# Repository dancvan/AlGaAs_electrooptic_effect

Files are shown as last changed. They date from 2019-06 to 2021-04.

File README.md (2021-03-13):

#AlGaAs_electro-optic_effect
This repository is intended to hold all related notes/work related to the measurement of the electro-optic effects (both the pockels and the piezoelectric effects) at the SU gravitational wave physics lab

Navigating this repository:

3D_prints:
- Contains all 3D printed designs used for this experiment (file formats: .stl, .shapr)

code:
- notebooks -> a high number of jupyter notebooks primarily used for quick computations and plotting. For instance, one notebook in lab_tools called beam_scans provides an easy routine to do a least squares fit from an .xlsx file.  
- fea_electrodes -> directory contains all files related to the simulation of the electrode system to produce a reasonable electric field estimate within the AlGaAs coating (both disk and split electrode systems)
- py_packages -> contains consistently used computations and operations (for instance, importing a model dataset from ltspice or the calibration of the meaasured error signal voltage spectra within the PDH loop to a displacement spectra
- finesse -> currently not utilized very much but might possibly be updated with tabletop simulations

documents:
- contains various books, datasheets, internal notes, and related publications that I found relevant to the project

measurements:
- all measured data. Categorized by measurement type and is stored within a directory that labels the date of the measurement taken.

results:
- contains a lot of .hdf5 files that can be traced back reading through the code/py_packages/pockels_cal.py calibration package. It also contains figures depicting experimental concept sketches and .stl files as well as group meeting updates that organize the results into something a little more comprehensive.

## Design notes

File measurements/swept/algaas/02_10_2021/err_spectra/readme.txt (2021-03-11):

This set of measurements starts from 2.6 kHz and goes up to 21 kHz. Peaks are driven at approximately 800 Hz intervals from 3kHz to 20.6kHz.

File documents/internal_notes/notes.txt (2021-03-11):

Stefan suggested looking at whether the frequency noise of the mephisto to see if it would be a limiting factor of our measurment
* When looking into frequency noise, you may ask how that would couple into our phase measurement?
* A key is to see how the circulating power differs when adjusting the frequency or the effective optical length of the cavity (see notes for calculating the circulating power and verifying that a change in frequency is equivalent to changing the effective optical length of the cavity)
* Once it was established that a change in frequency was equivalent to a change of effective optical length of the cavity, in terms of circulating power, we can calculate if the optical length change that we wish to measure relative to the total length of the cavity is larger than the change in frequency relative to the frequency of the laser. 
* Marty estimates that the change in optical length is 4.5e-10 m/V so I'll assume that for a half a meter cavity that the effect will be 9e-10 
* I estimate based on the specs sheet that a 1MHz change to a 281e12 Hz laser is around 3.54e-9
    - INCORRECT
    - This initial estimate is based on the slew rate of the laser
* The frequency noise of the laser is characterized in the mephisto spec sheets as a spectrum from 1Hz to 10 kHz 
    - How to translate this Hz/\sqrt(Hz) figure into phase noise?
    - Let's disentangle the figure....
    - The PSD for frequency noise essentially states how large the frequency wiggles at a particular frequency (feels kinda meta), but then again, what does this tell us about our phase noise?
    - We know that we can characterize length noise by taking the ratio of the change in length over the length, and equivalently we can do the same for frequency (take the change in frequency over the frequency to get frequency noise). But this doesn't seem explicit from the spectrum. the frequency noise is weighted by the amount of power it has in the spectrum... how to express that?
    - Let's start with the largest value in the freqeuncy amplitude noise spectrum, say 10^4 Hz/sqrt(Hz), let's translate this into phase noise:
        ~ the amplitude around 1Hz is 10^4 which means that there should be 10,000 Hz deviation around 1Hz?
        ~ This is definitely the case. Let's take the largest frequency variation and work with that in termso our our above expression: 
        ~ (10,000)/()

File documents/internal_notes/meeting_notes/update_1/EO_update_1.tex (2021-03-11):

%%%%%%%%%%%%%%%%%%%%%%%%%%%%%%%%%%%%%%%%%
% Beamer Presentation
% LaTeX Template
% Version 1.0 (10/11/12)
%
% This template has been downloaded from:
% http://www.LaTeXTemplates.com
%
% License:
% CC BY-NC-SA 3.0 (http://creativecommons.org/licenses/by-nc-sa/3.0/)
%
%%%%%%%%%%%%%%%%%%%%%%%%%%%%%%%%%%%%%%%%%

%----------------------------------------------------------------------------------------
%	PACKAGES AND THEMES
%----------------------------------------------------------------------------------------

\documentclass{beamer}

\mode<presentation> {

% The Beamer class comes with a number of default slide themes
% which change the colors and layouts of slides. Below this is a list
% of all the themes, uncomment each in turn to see what they look like.

%\usetheme{default}
%\usetheme{AnnArbor}
%\usetheme{Antibes}
%\usetheme{Bergen}
%\usetheme{Berkeley}
%\usetheme{Berlin}
%\usetheme{Boadilla}
%\usetheme{CambridgeUS}
%\usetheme{Copenhagen}
%\usetheme{Darmstadt}
%\usetheme{Dresden}
%\usetheme{Frankfurt}
%\usetheme{Goettingen}
%\usetheme{Hannover}
%\usetheme{Ilmenau}
%\usetheme{JuanLesPins}
%\usetheme{Luebeck}
\usetheme{Madrid}
%\usetheme{Malmoe}
%\usetheme{Marburg}
%\usetheme{Montpellier}
%\usetheme{PaloAlto}
%\usetheme{Pittsburgh}
%\usetheme{Rochester}
%\usetheme{Singapore}
%\usetheme{Szeged}
%\usetheme{Warsaw}

% As well as themes, the Beamer class has a number of color themes
% for any slide theme. Uncomment each of these in turn to see how it
% changes the colors of your current slide theme.

%\usecolortheme{albatross}
%\usecolortheme{beaver}
%\usecolortheme{beetle}
%\usecolortheme{crane}
%\usecolortheme{dolphin}
%\usecolortheme{dove}
%\usecolortheme{fly}
%\usecolortheme{lily}
%\usecolortheme{orchid}
%\usecolortheme{rose}
%\usecolortheme{seagull}
%\usecolortheme{seahorse}
%\usecolortheme{whale}
%\usecolortheme{wolverine}

%\setbeamertemplate{footline} % To remove the footer line in all slides uncomment this line
\setbeamertemplate{footline}[page number] % To replace the footer line in all slides with a simple slide count uncomment this line

\setbeamertemplate{navigation symbols}{} % To remove the navigation symbols from the bottom of all slides uncomment this line
}

\usepackage{graphicx} % Allows including images
\usepackage{booktabs} % Allows the use of \toprule, \midrule and \bottomrule in tables
%\usepackage {tikz}
\usepackage{tkz-graph}
\usepackage{hyperref}
\usepackage{ulem}
\hypersetup{
    colorlinks=true,
    linkcolor=blue,
    filecolor=magenta,
    urlcolor=cyan,
}
\GraphInit[vstyle = Shade]
\tikzset{
  LabelStyle/.style = { rectangle, rounded corners, draw,
                        minimum width = 2em, fill = yellow!50,
                        text = red, font = \bfseries },
  VertexStyle/.append style = { inner sep=5pt,
                                font = \normalsize\bfseries},
  EdgeStyle/.append style = {->, bend left} }
\usetikzlibrary {positioning}

%\usepackage {xcolor}
\definecolor {processblue}{cmyk}{0.96,0,0,0}
%----------------------------------------------------------------------------------------
%	TITLE PAGE
%----------------------------------------------------------------------------------------

\title[Short title]{Piezoelectric effect measurement update (Noise and initial design considerations)} % The short title appears at the bottom of every slide, the full title is only on the title page

\author{Ari Pedersen, Danny Vander-Hyde} % Your name
\institute[Syracuse University] % Your institution as it will appear on the bottom of every slide, may be shorthand to save space
{
Syracuse University\\ % Your institution for the title page
\medskip
}
\date{June 21, 2019} % Date, can be changed to a custom date

\begin{document}

\begin{frame}
\titlepage % Print the title page as the first slide
\end{frame}

\begin{frame}
\frametitle{Overview} % Table of contents slide, comment this block out to remove it
\tableofcontents % Throughout your presentation, if you choose to use \section{} and \subsection{} commands, these will automatically be printed on this slide as an overview of your presentation
\end{frame}

%----------------------------------------------------------------------------------------
%	PRESENTATION SLIDES
%----------------------------------------------------------------------------------------

%------------------------------------------------
\section{How big is the Piezoelectric effect?}
\begin{frame}{Some preliminary figures}
\begin{itemize}
  \item According to Marty Fejer $\frac{\partial \phi}{\partial \mathrm{E}} \approx 4.5*10^{-10} \frac{\mathrm{m}}{\mathrm{V}}$
  \item Conservatively we can attempt to create a setup that would generate Electric fields on the order of 10 V / 2.5 cm = \sout{400} \textcolor{red}{40} V/m \textcolor{red}{(Apparently I can't math)}
  \item Could also up the voltage and decrease the distance to get a larger effect
  \item This would lead to an effect of $1.8*10^{-8} \; [\mathrm{rad}]$ or $3.05*10^{-14} [\mathrm{m}]$
  \item This is for a single layer so we could multiply by the number of AlGaAs layers? (Maybe increases the effect by an order of magnitude?)
\end{itemize}
\end{frame}

\section{Competing with laser frequency noise}
\begin{frame}{Light source: Mephisto 2000 NE}
 \begin{figure}[H]
  \centering
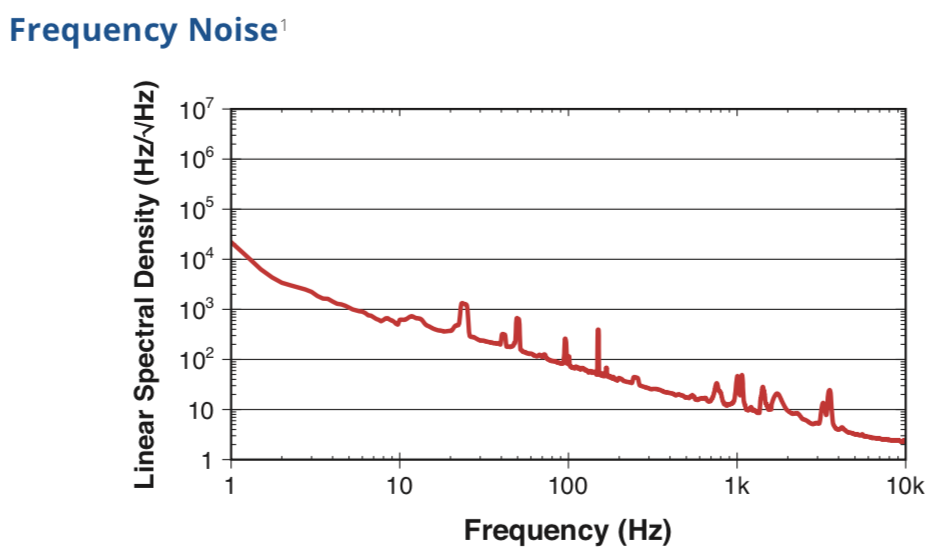
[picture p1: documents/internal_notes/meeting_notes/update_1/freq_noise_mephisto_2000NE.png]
  
 \end{figure}
\end{frame}

\begin{frame}{Frequency noise to phase noise}
\begin{itemize}
  \item Assuming that the largest laser frequency fluctuations ($\Delta f_\mathrm{laser}$) 11,500 Hz away from the carrier frequency. Can calculate this as phase noise $\big(\frac{\Delta f_{\mathrm{laser}}}{f_{\mathrm{laser}}}\big)$ on the order of $4.08*10^{-11}\; [\mathrm{rad}]$
  \item If we are to use a simple Fabry-Perot cavity to measure this effect, we would need:
$$\frac{\Delta f_{\mathrm{laser}}}{f_{\mathrm{laser}}}< \frac{\Delta L_{\mathrm{cav}}}{L_{\mathrm{cav}}}$$
Where I am considering $\Delta L_{\mathrm{cav}}$ to be the induced length change due to the piezoelectric effect.
  \item Assuming we have a 10 cm length cavity we can estimate $\frac{3.05*10^{-14}}{.01} = 3.05*10^{-12}\; [\mathrm{rad}]$ which lies an order of magnitude below the effect we wish to measure. :(
  \item Can modulate the electric field at some higher frequency where the frequency noise is less of an issue (how fast can we modulate the field and still notice the effect? $\rightarrow$ Impulse / Step response analysis)
\end{itemize}
\end{frame}

\begin{frame}{Frequency noise to phase noise \textcolor{red}{Stefan notes}}
\begin{itemize}
  \item Stefan mentioned that up to 10kHz you can assume that Piezo-electric response of the coating is flat up to 10kHz
  \item If we are to use a simple Fabry-Perot cavity to measure this effect, we would need:
$$\frac{\Delta f_{\mathrm{laser}}}{f_{\mathrm{laser}}}< \frac{\Delta L_{\mathrm{cav}}}{L_{\mathrm{cav}}}$$
Where I am considering $\Delta L_{\mathrm{cav}}$ to be the induced length change due to the piezoelectric effect.
  \item Assuming we have a 10 cm length cavity we can estimate $\frac{3.05*10^{-14}}{.01} = 3.05*10^{-12}\; [\mathrm{rad}]$ which lies an order of magnitude below the effect we wish to measure. :(
  \item Can modulate the electric field at some higher frequency where the frequency noise is less of an issue (how fast can we modulate the field and still notice the effect? $\rightarrow$ Impulse / Step response analysis)
\end{itemize}

\end{frame}

\begin{frame}{PDH locking}

\begin{itemize}
  \item First attempt to suppress laser frequency noise while keeping simple cavity design in mind.
  \item Black states (\href{https://youtu.be/tX884B8GrEE}{ref}) that a closed loop PDH system can suppress frequency noise ($n$) below the reference cavity pole frequency by a factor of $$\frac{1}{1 + H(s)*D(s)*K(s)}$$
Where H(s) [Hz/V] is the laser transfer function, D(s) [V/Hz] is the PDH transfer function, and K(s) is the servo gain.
  \item Don’t have exact values to propose but this could be a place to start.
  \item Propose we use the LIGO PMC we have on the AMM table as refrence cavity. (Might want to double check how destructive this could be to phase camera peeps)
  \item If this does not provide enough suppression, we might have to move on to an interferometer design.

\end{itemize}
\end{frame}

\section{Electrode / Sample mount}
\begin{frame}{Electrode design}
\begin{itemize}
  \item Am thinking of machining a thin square aluminum plate significantly larger than the size of the optic so to avoid field fringe effects. (Might need to do some quick calculations to establish the minimum size of this plate)
  \item Will also want to drill a hole in the center of the plate so to allow the beam to pass through to the AlGaAs sample without introducing any spatial defects to the intra-cavity beam. (Can do some calculations for optimal aperture size)
\end{itemize}
\end{frame}

\begin{frame}{Sample / electrode mount(s)}
  \item Traditional metallic optic mounts could introduce unwanted charge distributions. Need to think of ways around this. Here are some inital thoughts:
\\~\\
\textbf{In-air}
\begin{itemize}
    \item 3D printed flexure optic mount
    \item Could potentially be a simple one piece print
\end{itemize}
\\~\\
\textbf{In-vacuum}
\begin{itemize}
    \item Monolithic fused silica holder (Work on 3d printed concept? request to have made at Corning?)
    \item Don’t know how we would embed a fused silica holder in vacuum (suspended?) (clamped on table?)
\end{itemize}
\end{frame}

\end{document}

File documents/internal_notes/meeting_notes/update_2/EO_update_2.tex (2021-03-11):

%%%%%%%%%%%%%%%%%%%%%%%%%%%%%%%%%%%%%%%%%
% Beamer Presentation
% LaTeX Template
% Version 1.0 (10/11/12)
%
% This template has been downloaded from:
% http://www.LaTeXTemplates.com
%
% License:
% CC BY-NC-SA 3.0 (http://creativecommons.org/licenses/by-nc-sa/3.0/)
%
%%%%%%%%%%%%%%%%%%%%%%%%%%%%%%%%%%%%%%%%%

%----------------------------------------------------------------------------------------
%	PACKAGES AND THEMES
%----------------------------------------------------------------------------------------

\documentclass{beamer}

\mode<presentation> {

% The Beamer class comes with a number of default slide themes
% which change the colors and layouts of slides. Below this is a list
% of all the themes, uncomment each in turn to see what they look like.

%\usetheme{default}
%\usetheme{AnnArbor}
%\usetheme{Antibes}
%\usetheme{Bergen}
%\usetheme{Berkeley}
%\usetheme{Berlin}
%\usetheme{Boadilla}
%\usetheme{CambridgeUS}
%\usetheme{Copenhagen}
%\usetheme{Darmstadt}
%\usetheme{Dresden}
%\usetheme{Frankfurt}
%\usetheme{Goettingen}
%\usetheme{Hannover}
%\usetheme{Ilmenau}
%\usetheme{JuanLesPins}
%\usetheme{Luebeck}
\usetheme{Madrid}
%\usetheme{Malmoe}
%\usetheme{Marburg}
%\usetheme{Montpellier}
%\usetheme{PaloAlto}
%\usetheme{Pittsburgh}
%\usetheme{Rochester}
%\usetheme{Singapore}
%\usetheme{Szeged}
%\usetheme{Warsaw}

% As well as themes, the Beamer class has a number of color themes
% for any slide theme. Uncomment each of these in turn to see how it
% changes the colors of your current slide theme.

%\usecolortheme{albatross}
%\usecolortheme{beaver}
%\usecolortheme{beetle}
%\usecolortheme{crane}
%\usecolortheme{dolphin}
%\usecolortheme{dove}
%\usecolortheme{fly}
%\usecolortheme{lily}
%\usecolortheme{orchid}
%\usecolortheme{rose}
%\usecolortheme{seagull}
%\usecolortheme{seahorse}
%\usecolortheme{whale}
%\usecolortheme{wolverine}

%\setbeamertemplate{footline} % To remove the footer line in all slides uncomment this line
\setbeamertemplate{footline}[page number] % To replace the footer line in all slides with a simple slide count uncomment this line

\setbeamertemplate{navigation symbols}{} % To remove the navigation symbols from the bottom of all slides uncomment this line
}

\usepackage{graphicx} % Allows including images
\usepackage{booktabs} % Allows the use of \toprule, \midrule and \bottomrule in tables
%\usepackage {tikz}
\usepackage{tkz-graph}
\usepackage{hyperref}
\hypersetup{
    colorlinks=true,
    linkcolor=blue,
    filecolor=magenta,      
    urlcolor=cyan,
}
\GraphInit[vstyle = Shade]
\tikzset{
  LabelStyle/.style = { rectangle, rounded corners, draw,
                        minimum width = 2em, fill = yellow!50,
                        text = red, font = \bfseries },
  VertexStyle/.append style = { inner sep=5pt,
                                font = \normalsize\bfseries},
  EdgeStyle/.append style = {->, bend left} }
\usetikzlibrary {positioning}
%\usepackage {xcolor}
\definecolor {processblue}{cmyk}{0.96,0,0,0}
%----------------------------------------------------------------------------------------
%	TITLE PAGE
%----------------------------------------------------------------------------------------

\title[Short title]{Piezoelectric effect measurement update (Electrode plate design)} % The short title appears at the bottom of every slide, the full title is only on the title page

\author{Ari Pedersen, Danny Vander-Hyde} % Your name
\institute[Syracuse University] % Your institution as it will appear on the bottom of every slide, may be shorthand to save space
{
Syracuse University\\ % Your institution for the title page
\medskip
}
\date{July, 2019} % Date, can be changed to a custom date

\begin{document}

\begin{frame}
\titlepage % Print the title page as the first slide
\end{frame}

\begin{frame}
\frametitle{Overview} % Table of contents slide, comment this block out to remove it
\tableofcontents % Throughout your presentation, if you choose to use \section{} and \subsection{} commands, these will automatically be printed on this slide as an overview of your presentation
\end{frame}

%----------------------------------------------------------------------------------------
%	PRESENTATION SLIDES
%----------------------------------------------------------------------------------------

%------------------------------------------------
\section{Electrode plate design concept}
\begin{frame}{Geometries}
\begin{itemize}
\item Thin Circular Plate
\item Thin Square Plate
%% Insert diagram
%% Insert solution for E-field at center at a distance d from the plate
\item Write the strength of the E-field at particular ROI
\item Plate would be machined out of Aluminum and would be held at a constant potential with lab power supply
\item With this information we calculate an approximate surface charge density of (?) and we estimate that the distance between the electrode plates are at an optimal distance at (?)
\end{itemize}
\end{frame}

\section{Circular electrode plate with central hole}

\begin{frame}
\end{frame}

\begin{frame}{Circular electrodes with central hole}
\begin{itemize}
\item To the first order we might be able to say that the electric field at the region of interest (beam spot) is simply: 
$$
E_{\mathrm{total}} = \frac{V}{d}
$$
This assumes two infinitely sized parallel plate capacitor electrodes a distance d apart.
\item Estimated electric field from disk with hole (not considering fringe effects): 
$$
E_{A} = \frac{\sigma d}{2 \epsilon_\mathrm{o}}\bigg[ \frac{1}{\sqrt{d^{2} + r'^{2}}} + \frac{1}{\sqrt{d^2 + R^2}}\bigg]
$$

Considering both plates we can say that $E_{\mathrm{total}}$ at location A is: 

$$
E_{\mathrm{total}} = 2*E_{A}
$$
This expression considers the hole at the center of the electrodes, and the finite size of the electrode plates
\end{itemize}

\end{frame}
\begin{frame}{Optical considerations}
\begin{itemize}
\item Cavity Size / Beam spot size on sample
\item 
$$\frac{\Delta f_{\mathrm{laser}}}{f_{\mathrm{laser}}}< \frac{\Delta L_{\mathrm{cav}}}{L_{\mathrm{cav}}}$$
Where I am considering $\Delta L_{\mathrm{cav}}$ to be the induced length change due to the piezoelectric effect.
\item Assuming we have a 10 cm length cavity we can estimate $\frac{3.05*10^{-14}}{.01} = 3.05*10^{-12}\; [\mathrm{rad}]$ which lies an order of magnitude below the effect we wish to measure. :(
\item Can modulate the electric field at some higher frequency where the frequency noise is less of an issue (how fast can we modulate the field and still notice the effect? $\rightarrow$ Impulse / Step response analysis)
\end{itemize}

\end{frame}

\begin{frame}{PDH locking}

\begin{itemize}
\item First attempt to suppress laser frequency noise while keeping simple cavity design in mind. 
\item Black states (\href{https://youtu.be/tX884B8GrEE}{ref}) that a closed loop PDH system can suppress frequency noise ($n$) below the reference cavity pole frequency by a factor of $$\frac{1}{1 + H(s)*D(s)*K(s)}$$
Where H(s) [Hz/V] is the laser transfer function, D(s) [V/Hz] is the PDH transfer function, and K(s) is the servo gain. 
\item Don’t have exact values to propose but this could be a place to start. 
\item Propose we use the LIGO PMC we have on the AMM table as refrence cavity. (Might want to double check how destructive this could be to phase camera peeps)
\item If this does not provide enough suppression, we might have to move on to an interferometer design. 

\end{itemize}
\end{frame}

\section{Electrode / Sample mount}
\begin{frame}{Electrode design}
\begin{itemize}
\item Am thinking of machining a thin square aluminum plate significantly larger than the size of the optic so to avoid field fringe effects. (Might need to do some quick calculations to establish the minimum size of this plate)
\item Will also want to drill a hole in the center of the plate so to allow the beam to pass through to the AlGaAs sample without introducing any spatial defects to the intra-cavity beam. (Can do some calculations for optimal aperture size)
\end{itemize}
\end{frame}

\begin{frame}{Sample / electrode mount(s)}
\item Traditional metallic optic mounts could introduce unwanted charge distributions. Need to think of ways around this. Here are some inital thoughts:
\\~\\
\textbf{In-air}
\begin{itemize} 
    \item 3D printed flexure optic mount
    \item Could potentially be a simple one piece print
\end{itemize}
\\~\\
\textbf{In-vacuum}
\begin{itemize}
    \item Monolithic fused silica holder (Work on 3d printed concept? request to have made at Corning?)
    \item Don’t know how we would embed a fused silica holder in vacuum (suspended?) (clamped on table?)
\end{itemize}
\end{frame}

\end{document}

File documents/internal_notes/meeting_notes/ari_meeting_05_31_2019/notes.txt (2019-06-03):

After talking with ari the path forward starts with the following two things: 
* Calculate how how much the frequency noise contributes to a percieved phase differential (d\phi)/(d\nu_{laser})
* Send email to Stefan about whether or not we want to do this measurement in vaccum

## See photo for notes on Ari and my discussion

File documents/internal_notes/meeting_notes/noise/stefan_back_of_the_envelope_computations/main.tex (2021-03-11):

\documentclass{article}
\usepackage[utf8]{inputenc}

\title{EON back of the envelope noise computation}
\author{Daniel Vander-Hyde (interpreted from notes by Stefan Ballmer)}
\date{September 2019}

\usepackage{natbib}
\usepackage{graphicx}

\begin{document}

\maketitle

\section{Listing Marty's figure}
For a entire stratified surface of AlGaAs with alternating layers of 10 \% and 90 \% Al concentration the estimated Electro-optic noise contribution:

$$ \frac{d \phi}{dE} = 4.5*10^{-10} $$

which.. in terms of a physical length from a double pass through the coating:
$$\phi *2*k*\Delta x = \frac{4 \pi* \Delta x}{\lambda}$$

so the following is the estimated length change as we change the incident electric field: 

$$ \frac{d x}{dE} =3.8101*10^{-17}$$

Say we assume a 0th order field from our capacitor system that we are developing:
\\
\\
For a 100 Vpk potential difference across a 1cm separation capacitor we have a field of 10,000 [V/m]
\\
\\ 
This then implies a peak length change of $3.8*10^{-13}\; [m]$
\\
\\ 
Now let's convert this into a Power
\section{Conclusion}
``I always thought something was fundamentally wrong with the universe'' \citep{adams1995hitchhiker}

\bibliographystyle{plain}
\bibliography{references}
\end{document}

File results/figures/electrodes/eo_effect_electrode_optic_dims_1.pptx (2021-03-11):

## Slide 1

.87”

22 mm

2”

508mm

.43”

11mm

1”

25.4mm

.25”

6.35 mm

Assume disk thickness is 1/8 inch

Assume disk thickness is 3.17 mm

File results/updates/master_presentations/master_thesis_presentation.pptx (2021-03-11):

## Electro-optic effects in a HR AlGaAs coated mirror

Danny Vander-Hyde

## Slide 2

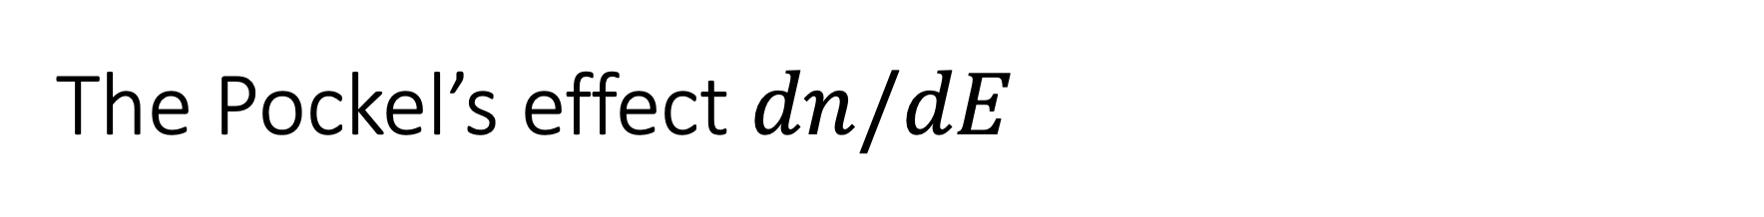
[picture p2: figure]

The Pockel’s effect, put quite simply is birefringence induced by an external Electric field across a material
The effect, predominantly in crystalline materials is caused by the

## Pockel’s effect for stratified media

## Measurement schema

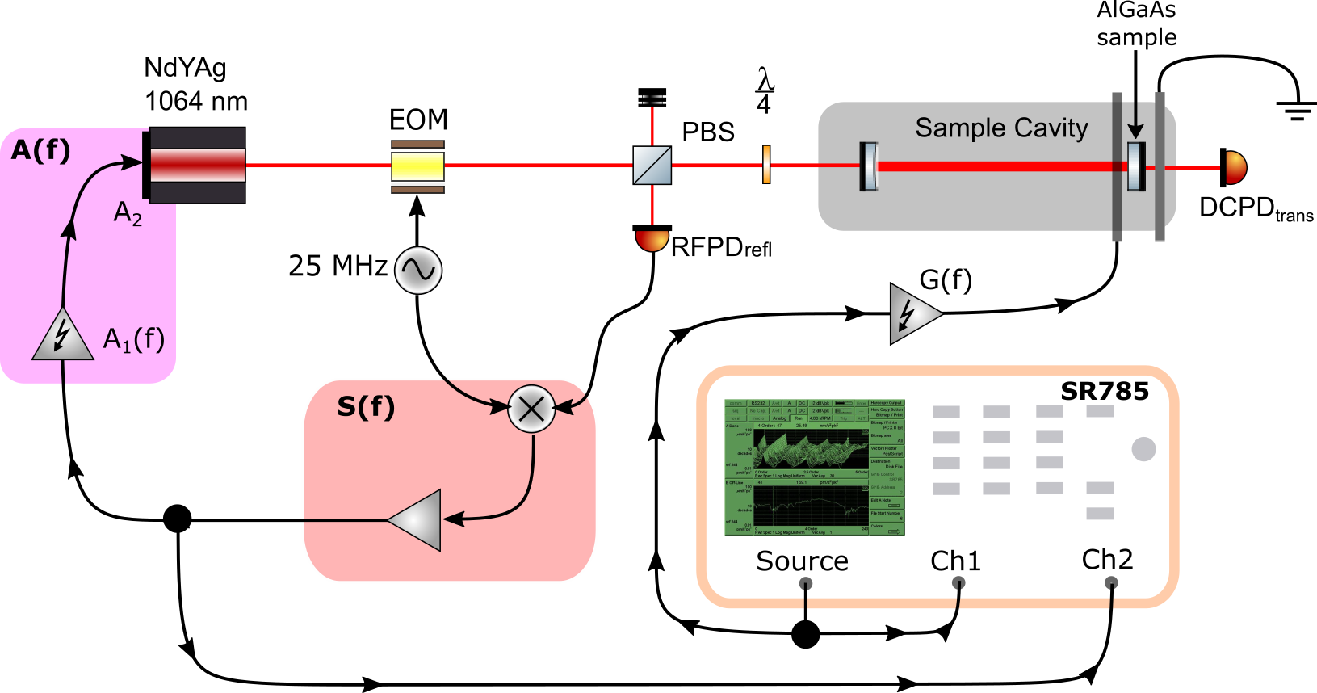
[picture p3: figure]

α(f)= (CH2(f))/(CH1(f))

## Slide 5

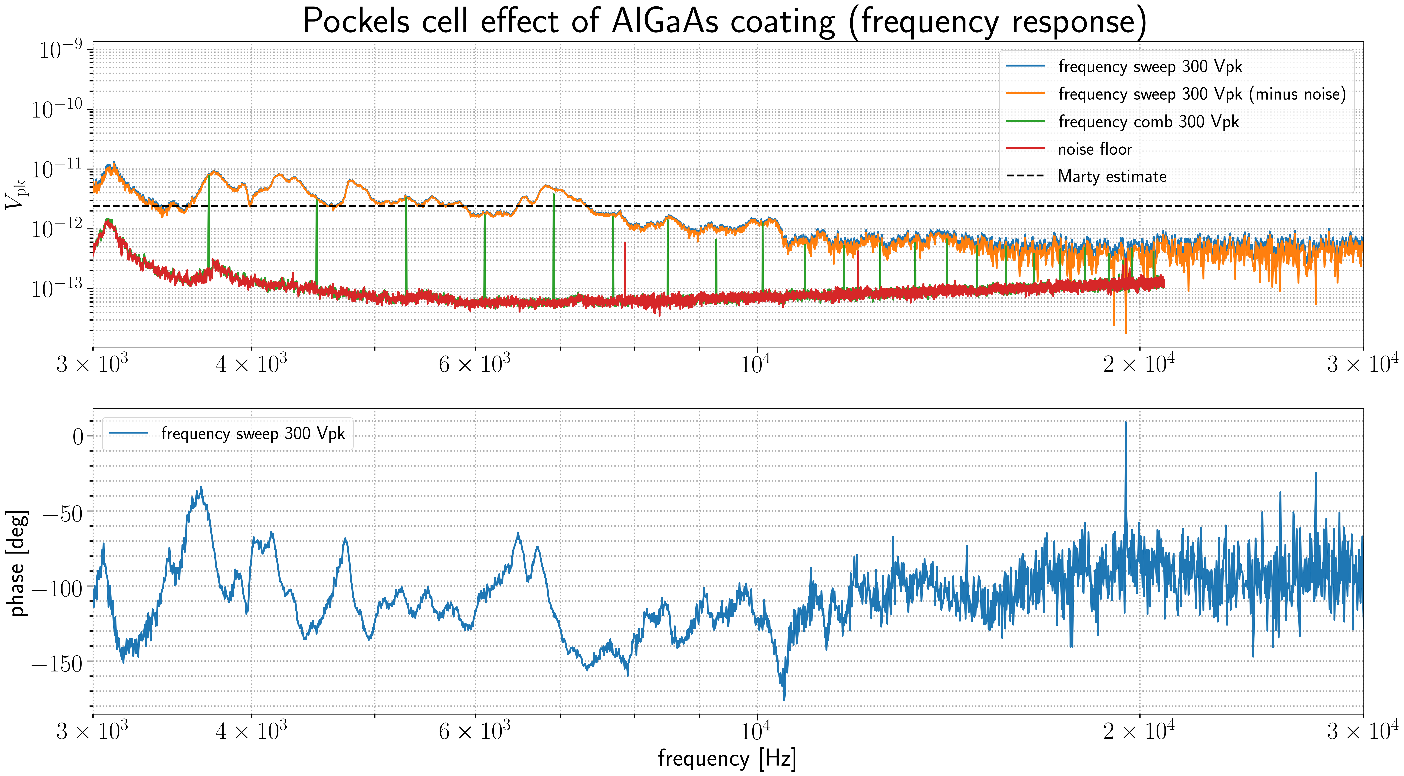
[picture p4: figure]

## EXTRA SLIDES

## Calibration (cont.)

There is a frequency dependent response of the injection to the electrodes that can be divided out and simplified:
α(f)=(CH2(f) ∗G(f))/(V_(electrodes)) (1)
We also know that the error signal spectra of the loop is probed by SR785_(CH2) (f) :
CH2(f)=(S(f)∗(signal [V]))/((1−OLG(f))) (2)
Where (signal [V]) is the uncalibrated voltage output from the mixer, S(f) is the FSS transfer function, and OLG(f) is the open loop gain of the PDH system.

## Calibration (cont.)

CH2(f)=S(f)∗((signal [V]))/(1−OLG(f)) (3)
And we can say OLG(f)= S(f)∗A_1 (f)∗ A_2 so :
[signal [m]]=CH2(f)∗A_1 (f)∗ A_2 ∗(1−OLG(f))/(OLG(f))∗(Lcav)/(2.8e14 [Hz]) (4)
Substitute (1) into (4):
[signal [m]]=(V_(electrodes) ∗α(f))/(G(f))∗A_1 (f)∗ A_2 ∗(1−OLG(f))/(OLG(f))∗(Lcav)/(2.8e14 [Hz]) (5)
M easured :α(f), OLG(f) , A_1 (f), A_2 , G(f), and L_(cav)
L_(cav) = .165 m

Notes: Rearrange equation 2 to solve for (signal) (replacement)

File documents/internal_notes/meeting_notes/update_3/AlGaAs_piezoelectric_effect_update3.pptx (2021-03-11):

## Piezoelectric Noise measurement (update 3)

Ari Pedersen, Danny Vander-Hyde

## Electrode design v2

- Using cylindrical Laplace solver in Matlab I modified the code to correct my statements in the first version (done in cartesian and was not correct assuming disk electrodes).
- To finalize the electrode design I wanted to optimize three features of the electrodes:
  1. The size of the disk
  2. The size of the hole in the disk
  3. Disk separation

## Electrode disk size

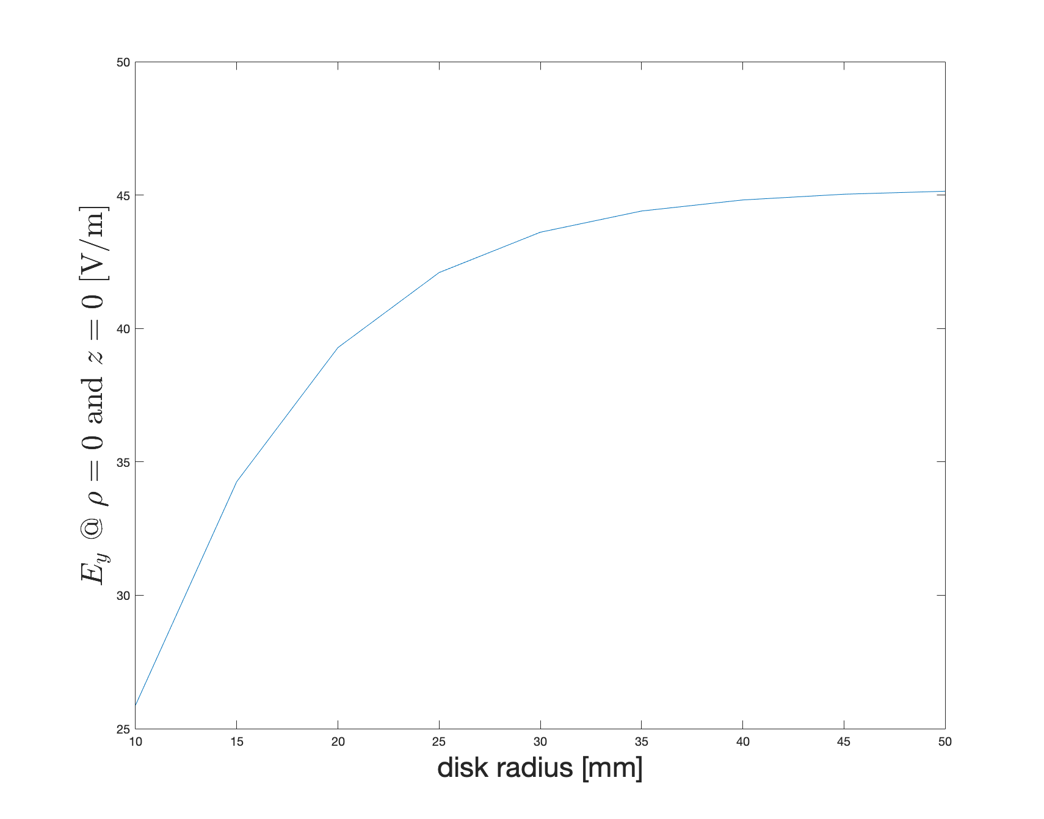
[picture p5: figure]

## Electrode hole size

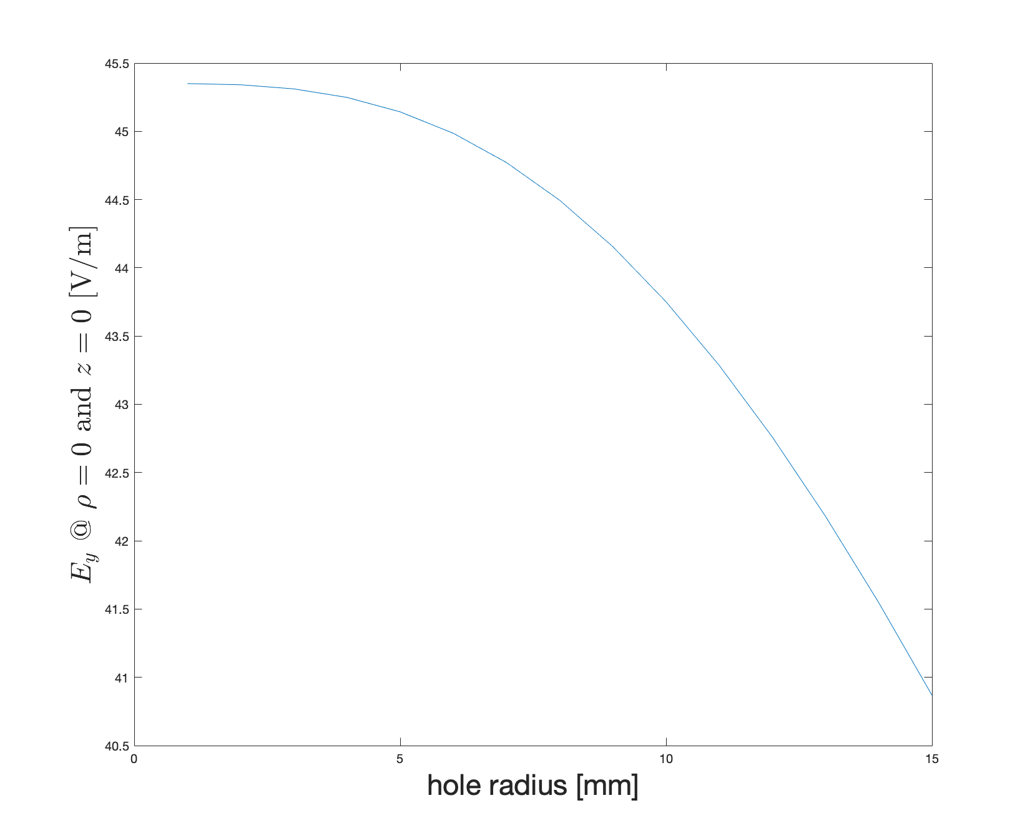
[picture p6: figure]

## Electrode disk separation

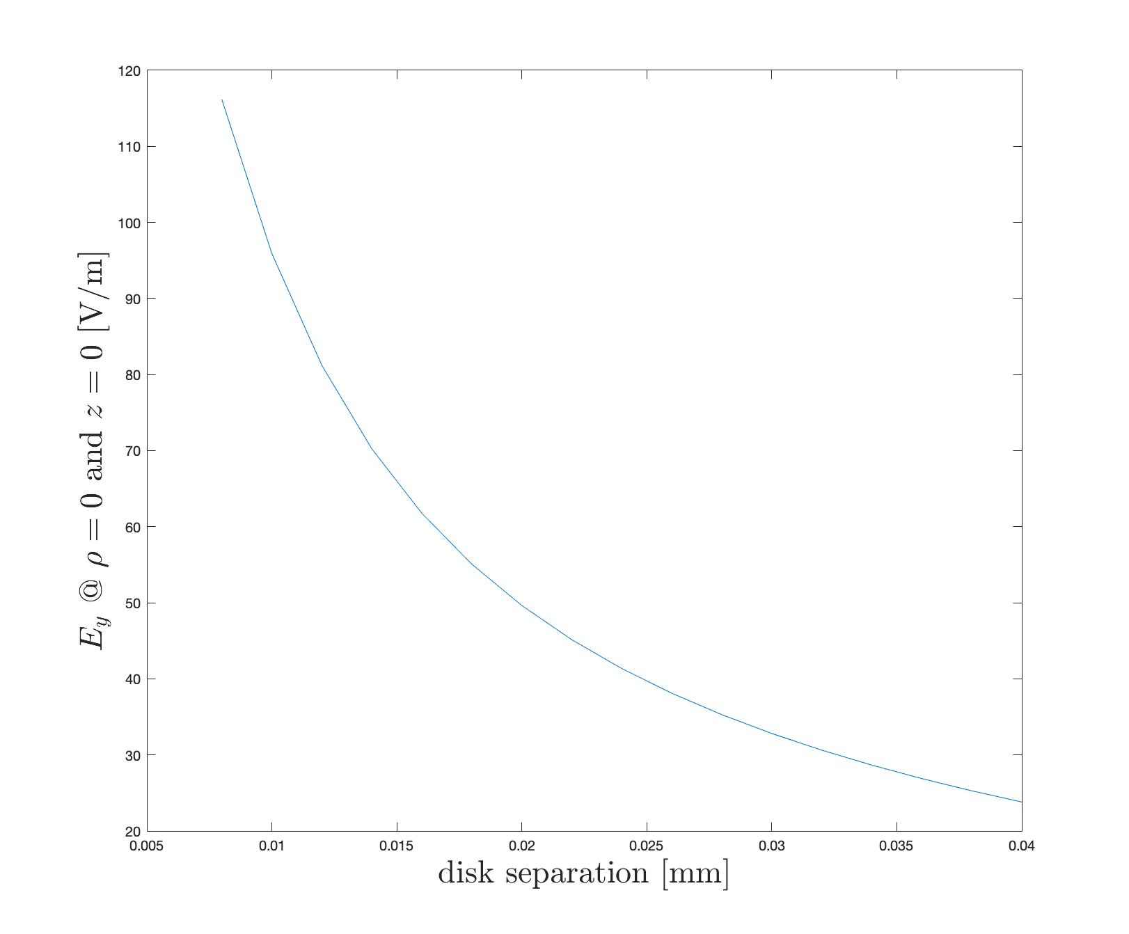
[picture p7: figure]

## Disk size and separation

.2 "

5mm

## Optical layout V0

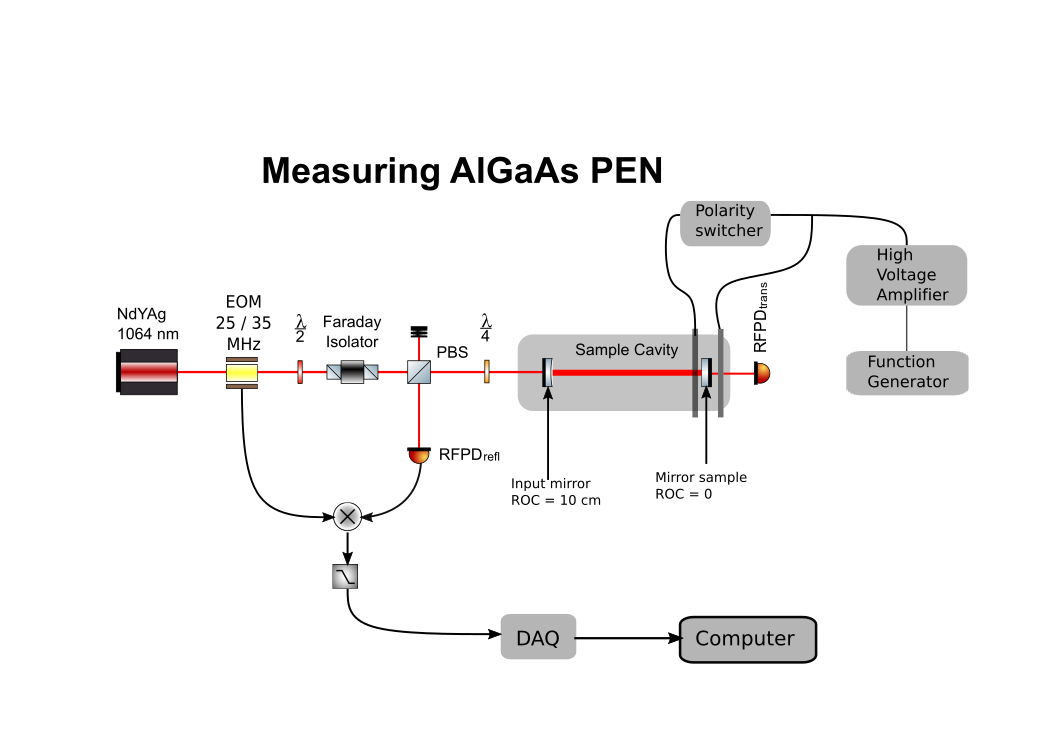
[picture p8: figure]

## Next steps

- COMSOL modelling comparison
- Further iterations of enclosure

## Some cool pictures (vary plate size \rho = 0)

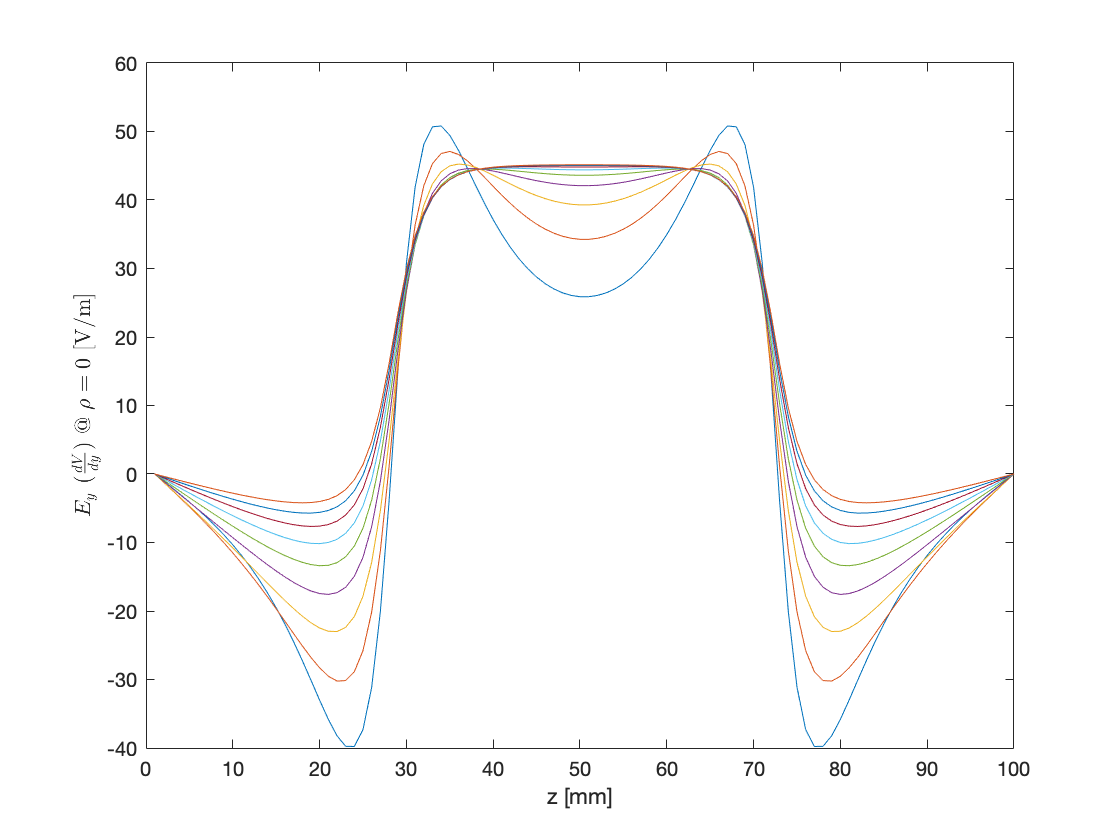
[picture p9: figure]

## Some cool pictures (varying hole size \rho = 0)

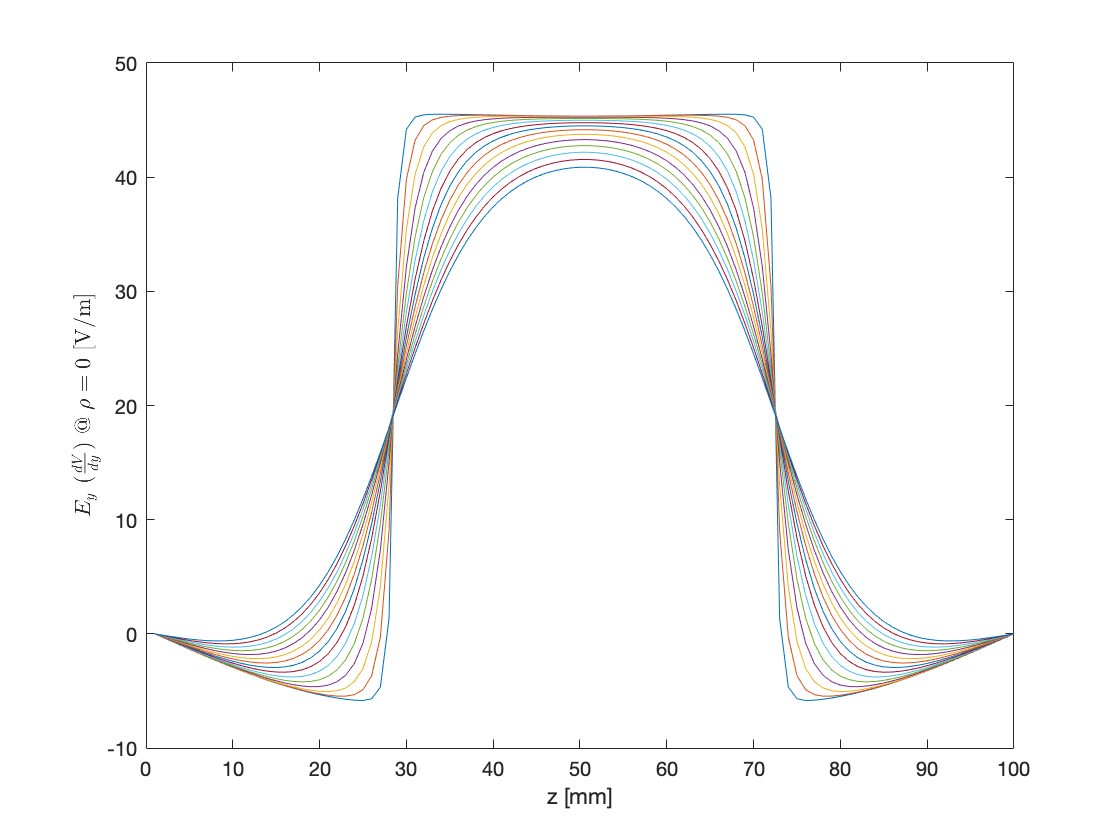
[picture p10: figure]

## Some cool pictures (vary plate separation \rho = 0)

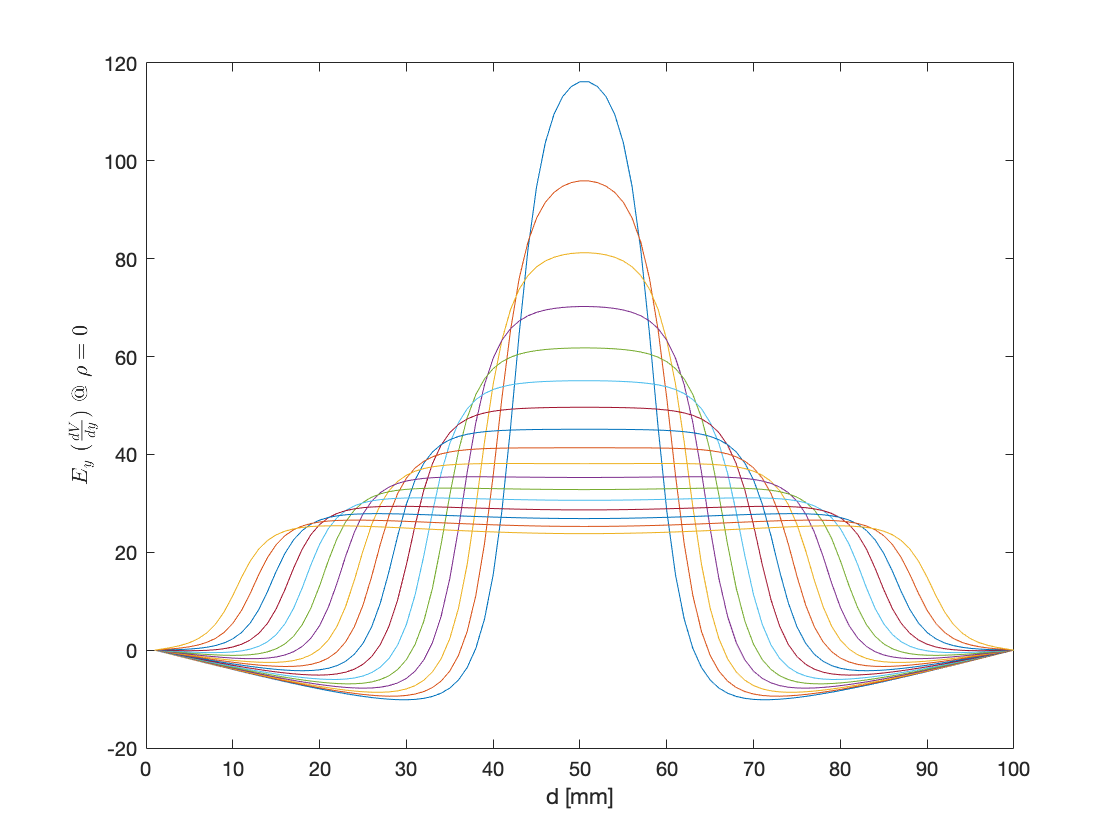
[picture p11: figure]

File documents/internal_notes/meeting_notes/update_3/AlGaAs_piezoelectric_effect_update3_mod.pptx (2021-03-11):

## Measuring electro-optic noise of AlGaAs (electrode design and schema v1)

Ari Pedersen, Danny Vander-Hyde

## Electrode disk size

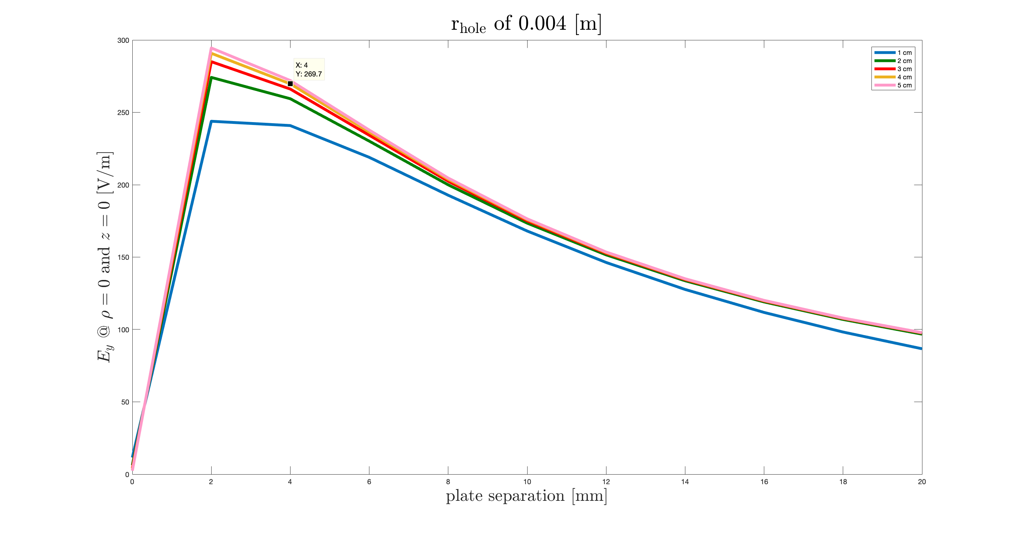
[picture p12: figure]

Comparing 4 and 5 cm the difference is no larger than .5% in field strength between 10-20 mm of disk separation
Comparing 3 and 4 cm the difference is no larger than .6% between 10-20 mm of disk separation
Comparing 3 and 2 cm the difference is no larger than .82% between 10-20 mm of disk separation
Comparing 2 and 1 cm the difference is no larger than 11.7% between 10-20 mm of disk separation
* Note: 2 [V] potential difference set between the plates

## Electrode disk size (cont.)

- For a 4 mm electrode hole radius (conservative estimate for optical considerations), we have some freedom to choose between a 2.5 inch to 4 inch disk without much loss of field strength at the origin
  - Note: not flux of some region, just a point at the origin.

## Optical layout V1

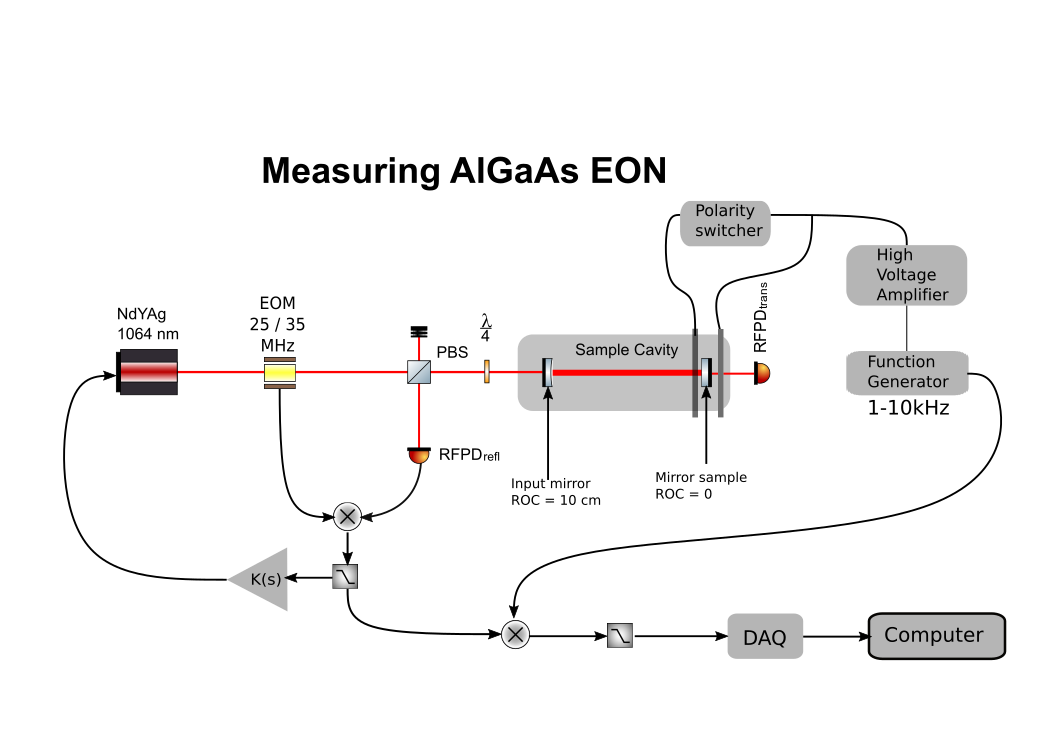
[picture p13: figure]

## Electrode disk size (extra)

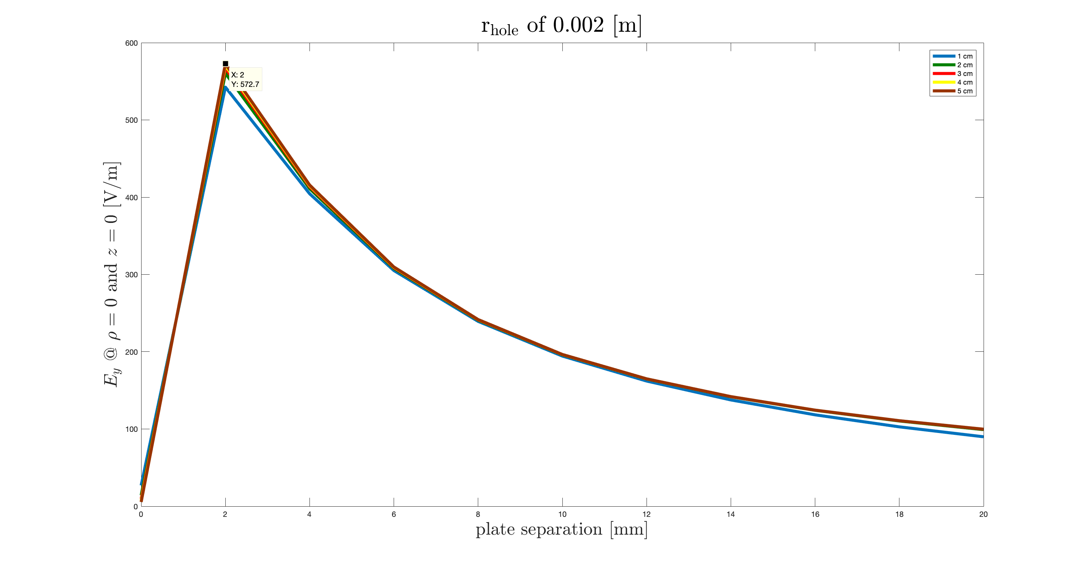
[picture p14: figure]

Comparing 4 and 5 cm the difference is no larger than .08% in field strength between 10-20 mm of disk separation
Comparing 3 and 4 cm the difference is no larger than .08% between 8-20 mm of disk separation
Comparing 3 and 2 cm the difference is no larger than .54% between 8-20 mm of disk separation
Comparing 2 and 1 cm the difference is no larger than 10.3% between 8-20 mm of disk separation
* Note: 2 [V] potential difference set between the plates

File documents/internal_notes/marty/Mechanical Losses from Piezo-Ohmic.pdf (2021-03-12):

Mechanical Losses from Piezoelectric-Ohmic Loss Coupling
M. M. Fejer
May 29, 2020
1. Introduction
There exist more sources of thermodynamic noise in non-centrosymmetric semiconducting media than in conventional isotropic insulators. One example is the coupling of density fluctuations in charge carriers through the accompanying space-charge fields combined with the electro-optic effect into refractive index changes. In a bulk GaAs mirror substrate, this mechanism would cause ~105 larger linear spectral density of path length fluctuations than would the free-carrier dispersion alone (which is the only such coupling in centrosymmetric silicon).
Another mechanism is ohmic dissipation due to currents induced by the piezo-electric effect in an AlGaAs mirror. With an oscillatory Levin pressure field applied to the surface of an AlGaAs mirror, the piezo-electric effect generates an effective current through the volume of the mirror, which dissipates power due to the ohmic resistance of the mirror material. This process is analyzed here.
2. Piezoelectric effect in zincblende semiconductors
For our purposes, the pertinent part of the piezo-electric response in Voight notation is that a stress TJ generates a dipole moment density Pi described by the piezo-electric strain constants diJ. In materials like AlGaAs that are in the 43m point group, the only non-zero tensor components are d14 = d25 = d36 ,which are all conventionally referred to as d14.. For a [001] oriented AlGaAs mirror, the pertinent relation is then
z | 14 6 P | dT = | (1)
where we recall that in the Voight notation T6 | xy = σ . To the extent that the stress is uniform
through the thickness of the mirror layer, the polarization density is as well. Recalling that Ñ· P enters into Maxwell’s equations as an effective charge density, this charge will vanish except at the surfaces of the mirror (which for simplicity we consider for the present simply as a uniform layer of
GaAs), where it creates an effective sheet charge density z | 14 6 ± =± =± q | P | dT at the top and bottom
interfaces, respectively.
3. Electrical model of piezo-electric layer
To model the electrical behavior of the piezo-electric layer, we can think of an area A of the mirror as a leaky capacitor, with the capacitance
0 C | Al = εε / | (2)
shunted by a resistance

Rl | A = / σ | (3)
where l is the thickness of the layer, σ is the conductivity of the mirror, and ε is the dielectric constant.
For a stress with a sinusoidal time dependence exp( ) it ω , the surface charge will also be oscillatory, so will enter as current driving the capacitor

14 6

dq | it I A | i Ad T e
dt
ω = | = ω | (4)
We now have an elementary circuit theory problem to solve. The real part of the impedance of the leaky capacitor is
Re | 2 2 2 | 22 1 | 1
R | R Z
ω CR | ωτ = | = + | +

(5)
where the RC time constant

0 RC

εε
τ
σ
≡ | = | (6)
is equivalent to Maxwell relaxation time for the mirror material. The average power dissipated is then

( )
2 2
0 Re | 14 6 | 22
2 | 2
14 | 2
22 | 6
| 2
14 | 2
22 | 6
0
1 | 1
2 | 2 | 1
1 | 1
2 1
| 2 1

diss

diss

R P | I Z | Ad T

Ad l
T
| P | d
T
| Al | ω
ωτ
| ω
ωτ σ
ω | ωτ
| | ωτ εε
= | = | +
= | +
Þ | = · | +

(7)
where the second form follows with Eqs. (4) and (5), the third form with Eq. (3), and the final with Eq. (6). The final form will be recognized as the average power dissipated per unit volume.
4. Equivalent φ
Comparing Eq. (7) with the usual expression for the loss for shear field in a thin layer,

2
66 66 66
2 | 2
6 | 6
66 66 | 2 | 66
66 | 66
vol | 2
2 | 2

diss P
c | S
T | T
c
c | c

ω φ

ω | ω φ | φ

=

= | =

(8)
where c66 and φ66 are the shear stiffness and the loss angle, we see that the piezo-electric loss mechanism is equivalent to adding an additional effective loss angle of

2
14
66, | 66 | 22

0 1 eq

d
c

ωτ φ
εε | ωτ = | +

(9)
With d14 = 2.6 x 10-12 C/nt, ε = 12.5, c66 = c44 = 6 x 1010 nt/m2, we find

3
66, | 22 4 10
1 eq

ωτ φ
ωτ
- =×
+

(10)

5. Discussion
With the result in Eq. (10), the equivalent loss is clearly large enough to be a serious problem near the peak dissipation frequency ω τ ~1/ . Measurements at room temperature on AlGaAs mirrors indicate a much lower value for the shear loss, <10-5. This is not necessarily contradictory, since the relaxation time for GaAs, even at the low carrier densities in the AlGaAs mirrors should be sub-microsecond, putting the peak loss at frequencies well above the LIGO range. This explanation, though, is at odds with the recent Syracuse measurements of the electro-optic sensitivity, which was within a factor of ~2 of the result computed in the absence of carrier screening effects. Since both these calculations are relatively straightforward (other than carrier transport effects), and depend on no extrinsic parameters other than the conductivity (or equivalently the dielectric relaxation time), it is not clear yet how theory and experiment can be reconciled. It would seem likely that effects of the heterojunctions on the carrier transport normal to the layers are likely involved.
One possible explanation would be if the GaAs layers had a very short τ and the AlGaAs layers had a very long τ . In that the GaAs layers would have their loss peak at frequencies above the LIGO band while the loss in the AlGaAs layers would peak at frequencies below the LIGO band. Under those conditions, the applied electric field in the EO experiment would be screened out of the GaAs layers but would appear in the AlGaAs layers, so that the sensitivity would be reduced by a factor of ~2. This should be a computable question, if the doping in the two layers were known.
Another point to consider is that the conductivity will decrease exponentially with temperature as carriers freeze out in the cryogenic regime, and thus the conductivity will decrease (somewhat mitigated by an increase in mobility), the relaxation time will increase, and the peak frequency will move closer to the LIGO range. Since the other parameters in the piezoloss expression are weak functions of temperature, the piezo mechanism should be considered in understanding any unexpected increases in the observed loss at low temperatures.

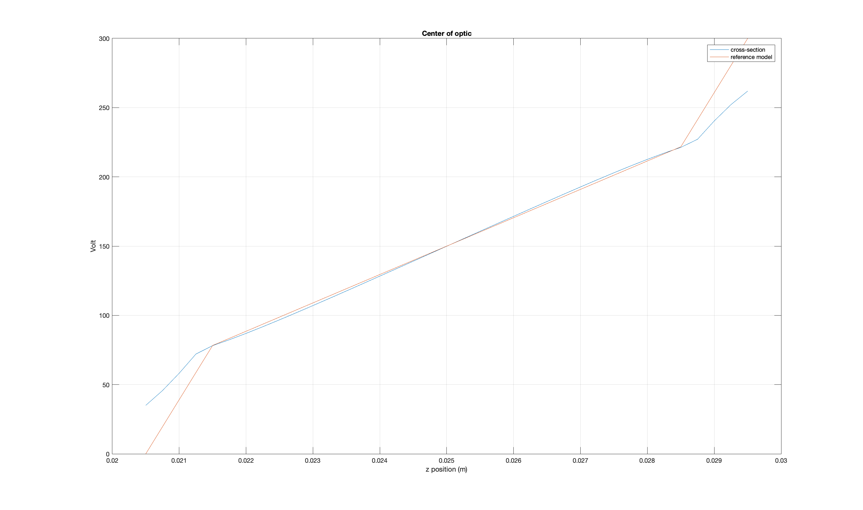
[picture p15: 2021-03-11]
code/fea_electrodes/matlab_script_stefan/poisson/results_04_07_2020/center_of_optic_voltage.png

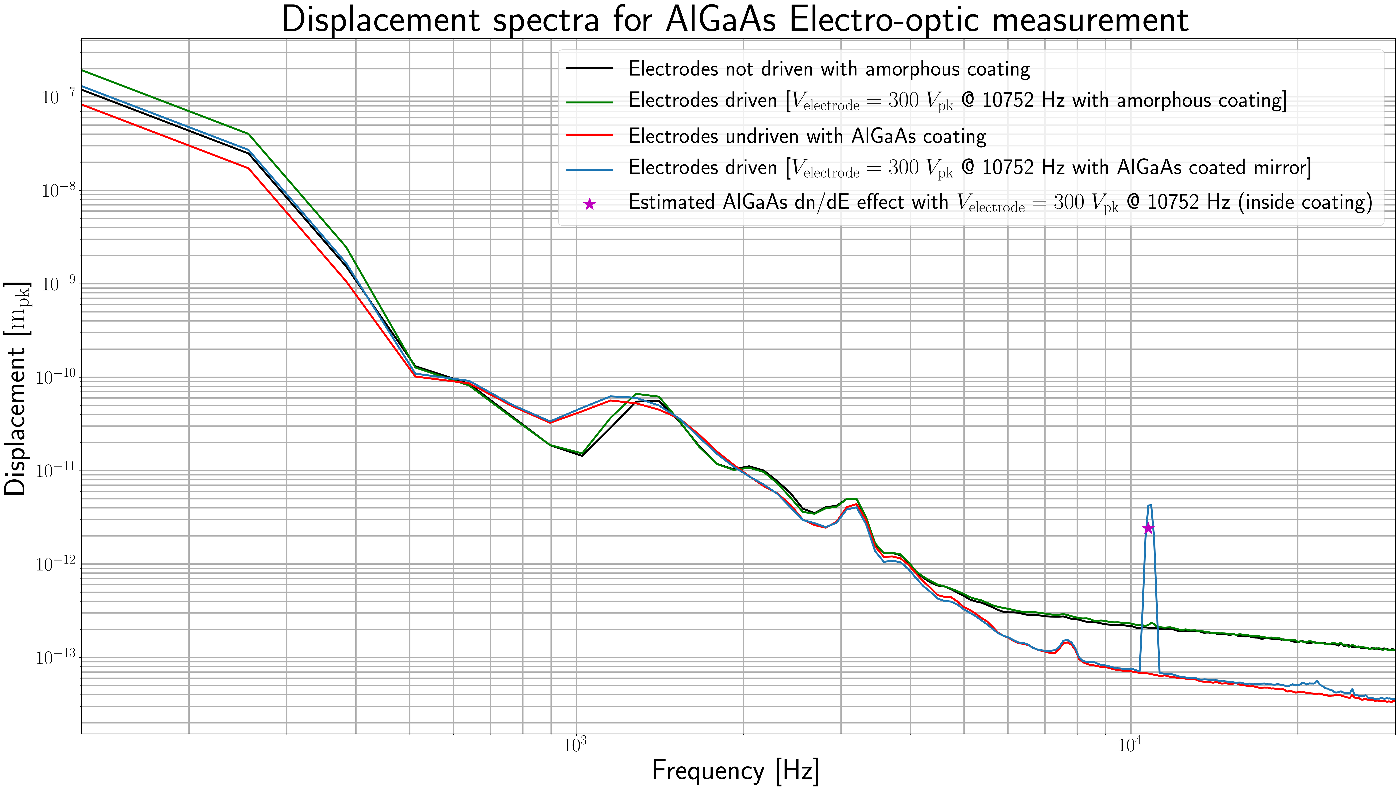
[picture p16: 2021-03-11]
measurements/single_frequency/algaas/04_26_2020/AlGaAs_driven/displacement_spectra_w_algaas_actuation_2MHz.png

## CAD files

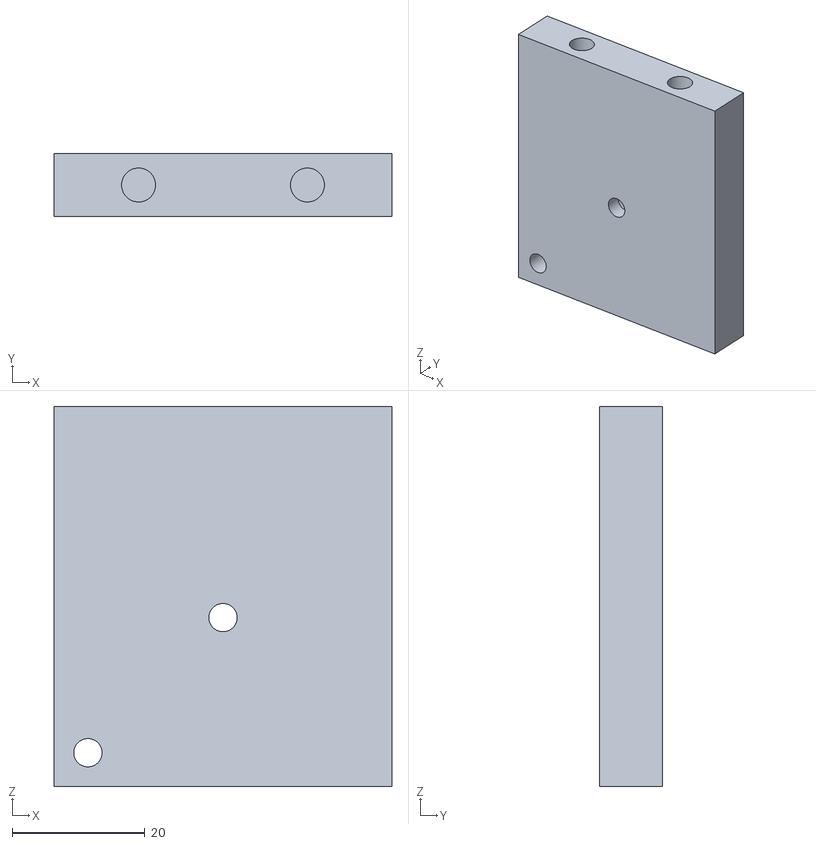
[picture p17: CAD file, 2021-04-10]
3D_prints/design_v2/assembly/iter_a/tip_tilt_mount_pt1.stl
50.8 x 9.53 x 57.1

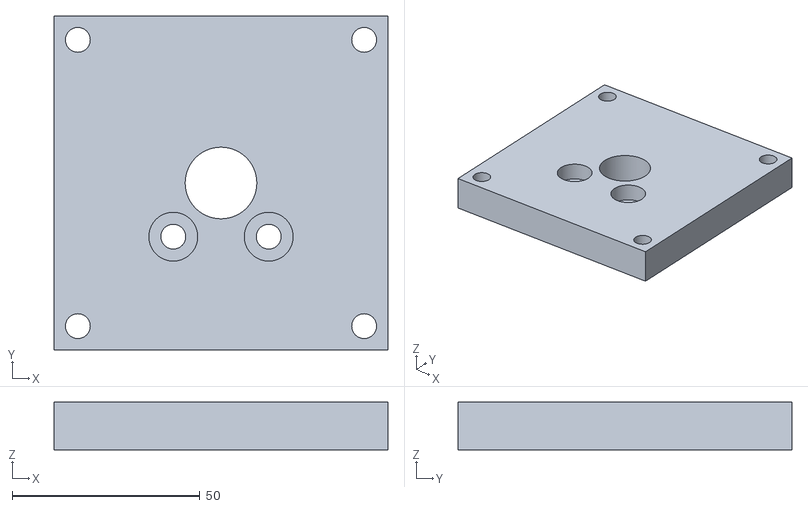
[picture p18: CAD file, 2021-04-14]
3D_prints/design_v2/assembly/Iter_b/MACOR_bp_iterationb.stl
88.9 x 88.9 x 12.7

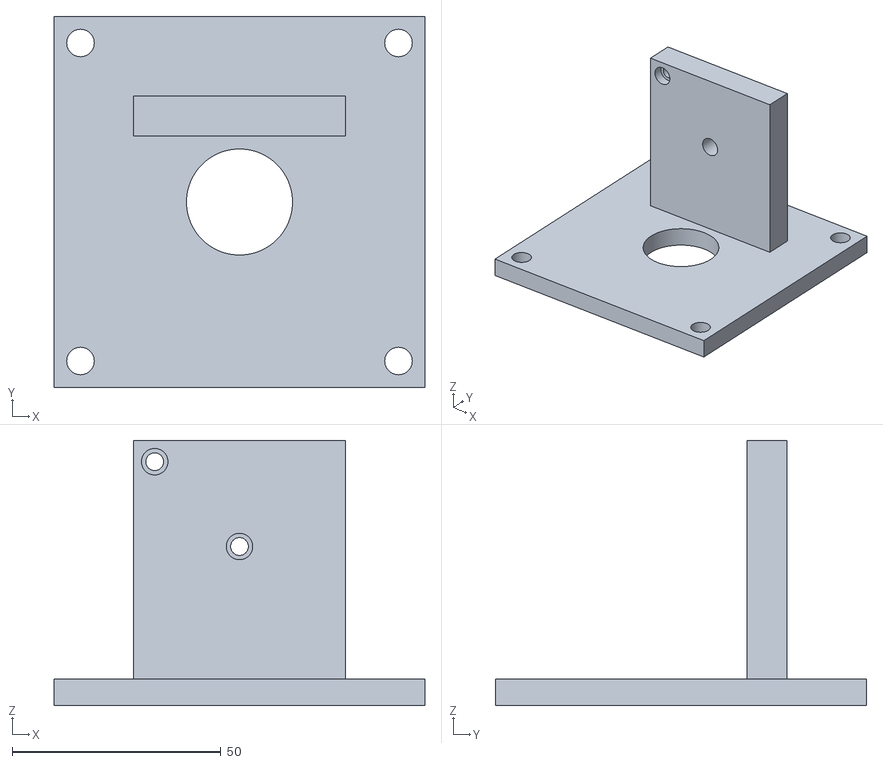
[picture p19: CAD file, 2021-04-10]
3D_prints/design_v2/monolith/MACOR_bp1_rotated.stl
88.9 x 88.9 x 63.5

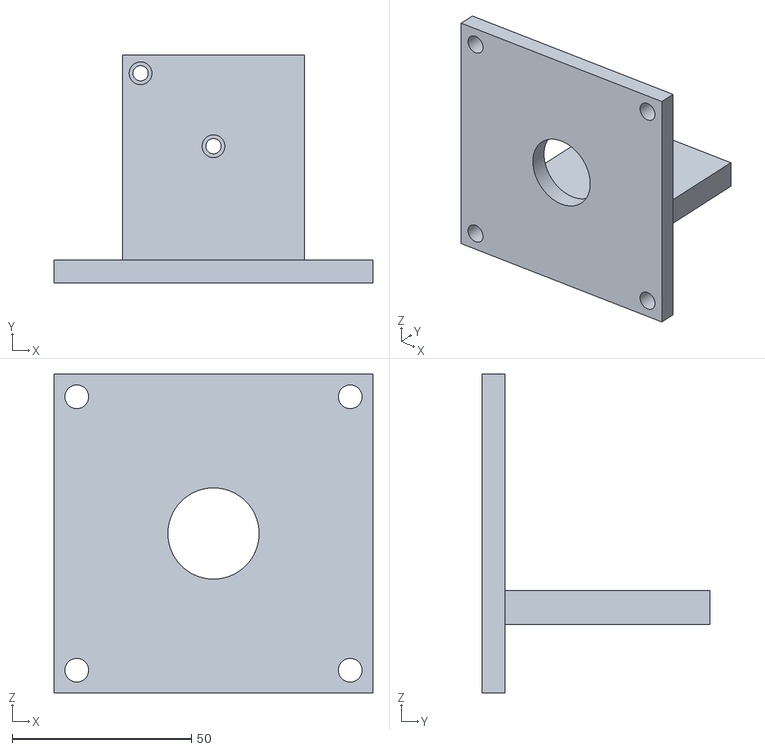
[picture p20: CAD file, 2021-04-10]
3D_prints/design_v2/monolith/MACOR_bp1.stl
88.9 x 63.5 x 88.9

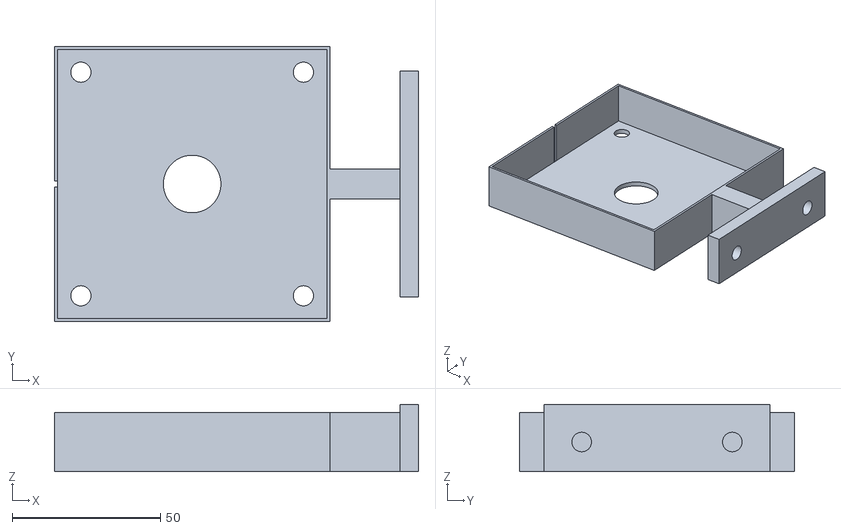
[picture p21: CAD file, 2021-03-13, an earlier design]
3D_prints/design_v0/optic_and_electrode_mount.stl
122.8 x 92.9 x 22.7

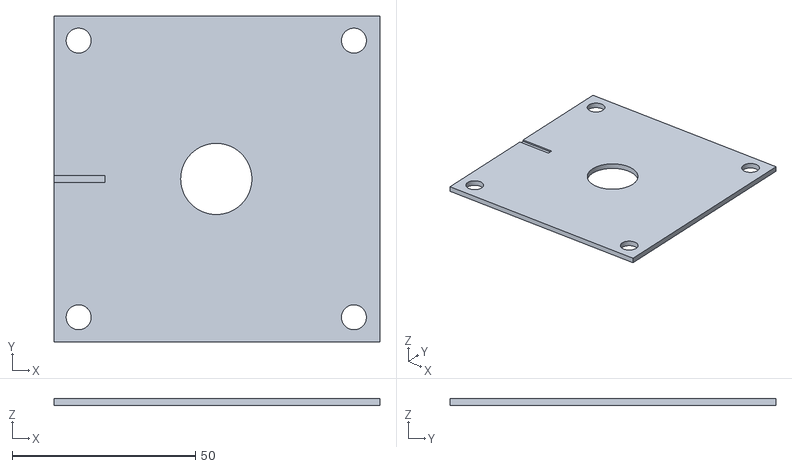
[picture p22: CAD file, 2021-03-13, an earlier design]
3D_prints/design_v1/disk/electrode_backing.stl
88.9 x 88.9 x 2.00

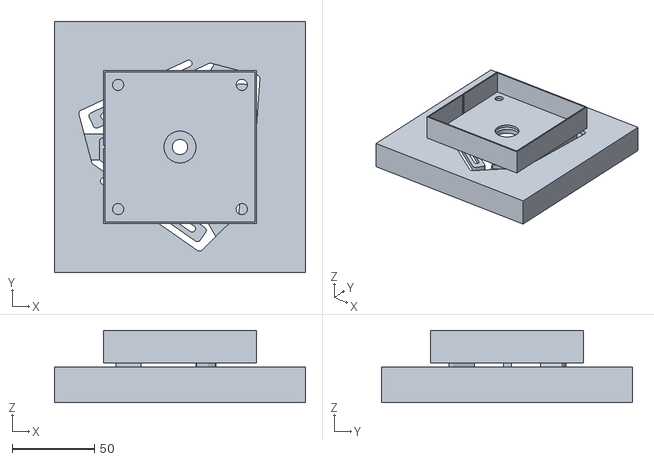
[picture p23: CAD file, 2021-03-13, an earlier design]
3D_prints/design_v1/optic_and_electrode_mount_orthoplanar_spring.stl
152.4 x 152.4 x 44.0

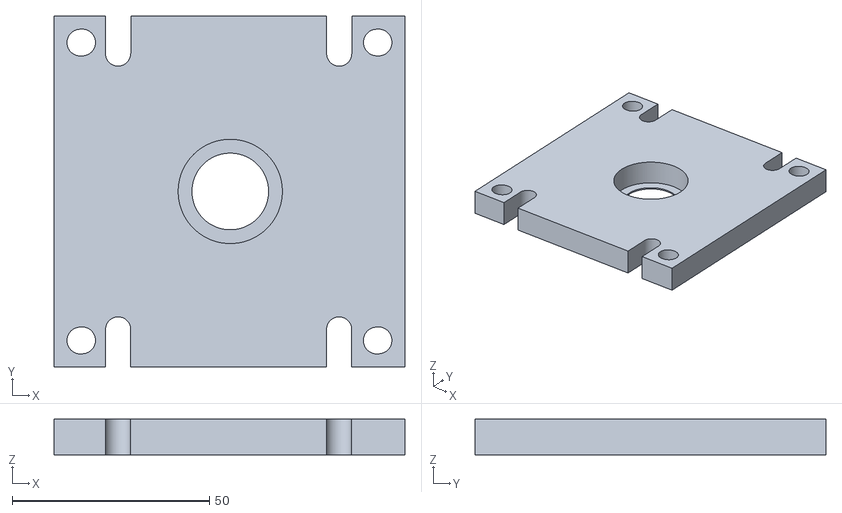
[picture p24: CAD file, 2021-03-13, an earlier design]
3D_prints/design_v1/split/split_electrode_optic_holder.stl
88.9 x 88.9 x 9.00

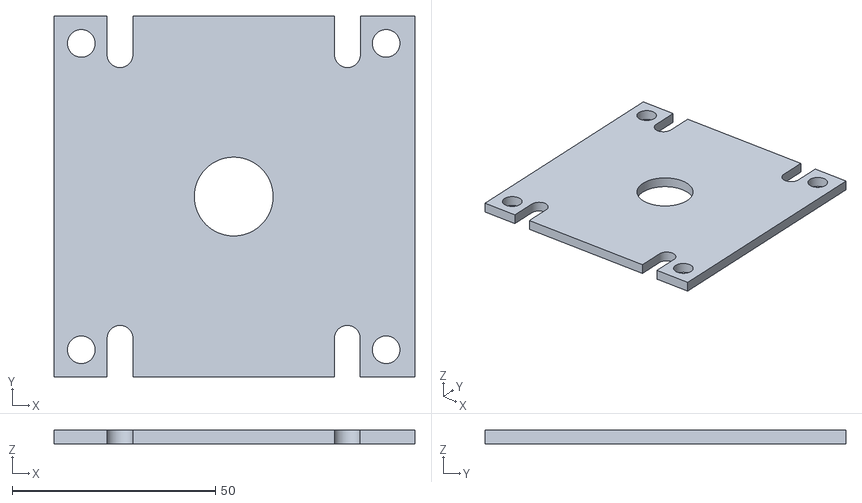
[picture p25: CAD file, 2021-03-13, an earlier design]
3D_prints/design_v1/split/split_electrode_backing.stl
88.9 x 88.9 x 3.50

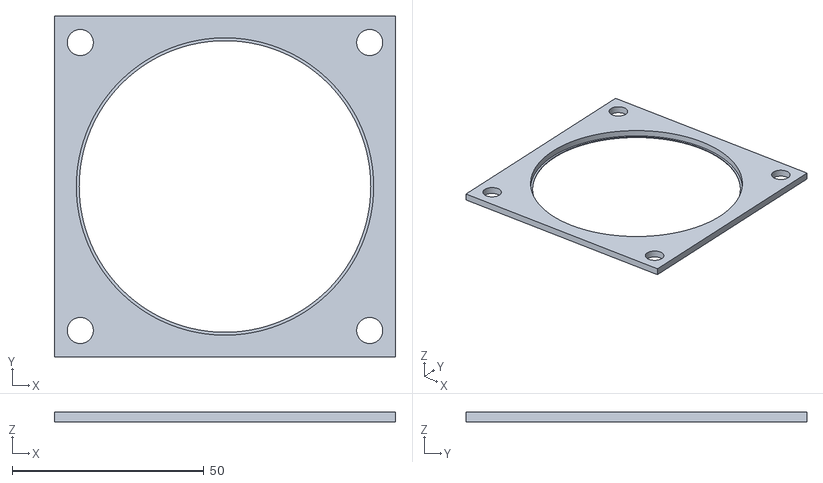
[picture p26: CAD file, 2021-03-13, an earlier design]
3D_prints/design_v1/disk/electrode_brace.stl
88.9 x 88.9 x 2.50

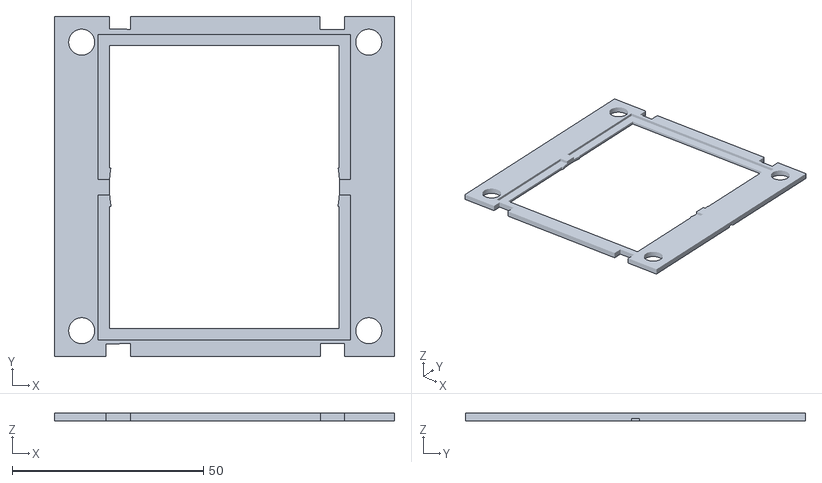
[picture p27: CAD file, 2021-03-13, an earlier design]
3D_prints/design_v1/split/split_electrode_brace.stl
88.9 x 88.9 x 2.00

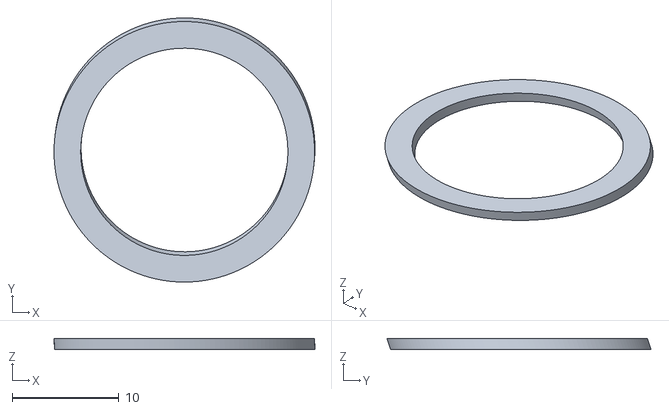
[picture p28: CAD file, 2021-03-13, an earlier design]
3D_prints/design_v1/disk/optic_backing.stl
24.4 x 24.7 x 1.00

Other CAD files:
3D_prints/design_v2/assembly/iter_a/tip_tilt_mount_pt2.stl
3D_prints/design_v1/disk/optic_holder.stl

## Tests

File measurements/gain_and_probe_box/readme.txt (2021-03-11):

This directory has all information regarding the construction and design of a custom circuit board with an adjustable non-inverting amplifier with a probe stage that reduces the amplifer output (orders of magnitude smaller via a voltage divider).

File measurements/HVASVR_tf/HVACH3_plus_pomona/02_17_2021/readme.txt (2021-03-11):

This HVA transfer function was measured between 100 Hz to approximately 102.4 kHz and was taken with the gain dial set to 75% of its maximum value

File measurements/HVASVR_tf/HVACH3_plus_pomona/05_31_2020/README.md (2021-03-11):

Amplitude knob less than halfway (37.5% of max)

range1 : 128Hz-100kHz (200 points)
range2 : 1Hz -50kHz (200 points)
range3 : 1Hz-10kHz (200 points)

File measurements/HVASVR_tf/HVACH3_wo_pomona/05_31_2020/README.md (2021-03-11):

Amplitude knob less than halfway (37.5% of max)

1hz-102.4khz no pomona (300 points)

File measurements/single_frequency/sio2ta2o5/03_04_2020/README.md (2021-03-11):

These measurements were taking with the following FFT averaging settings:
Continuous exponential averaging
1000 averages
128 Hz bin width
THe windowing settings were the following:
BMH

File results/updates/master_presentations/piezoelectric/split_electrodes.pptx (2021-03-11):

## Piezoelectric field in HR AlGaAs coating (split electrode design)

Danny Vander-Hyde

## Electric field injection

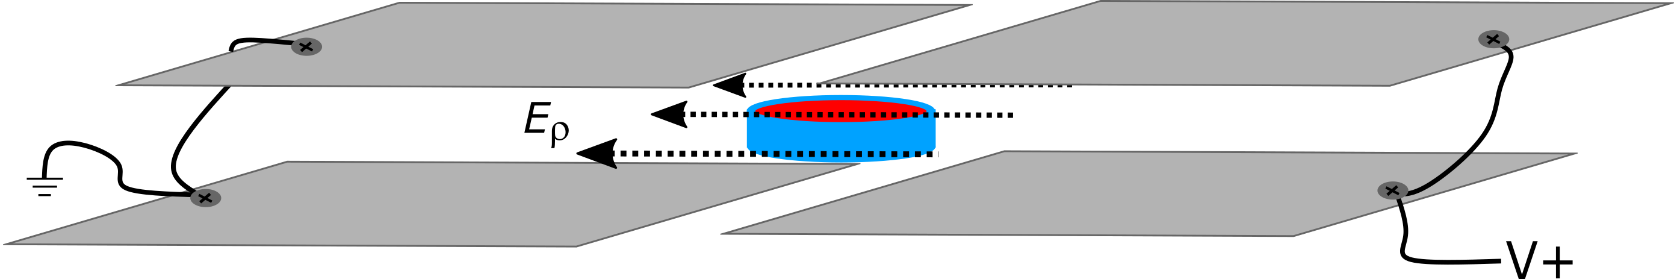
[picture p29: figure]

Plate dimensions: 66mm x 38mm
Plate separation along z-axis: 9mm
Slit size: 3mm
V+ = 0-300V

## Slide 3

Potential map

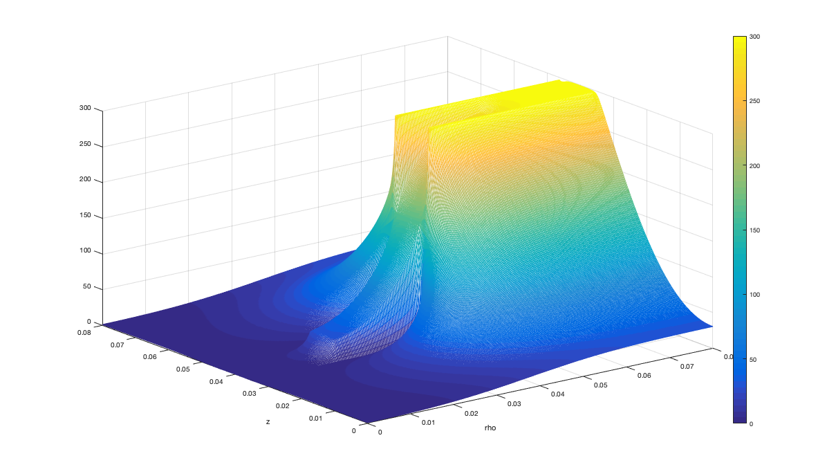
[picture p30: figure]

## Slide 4

Electric field estimate (transverse field)

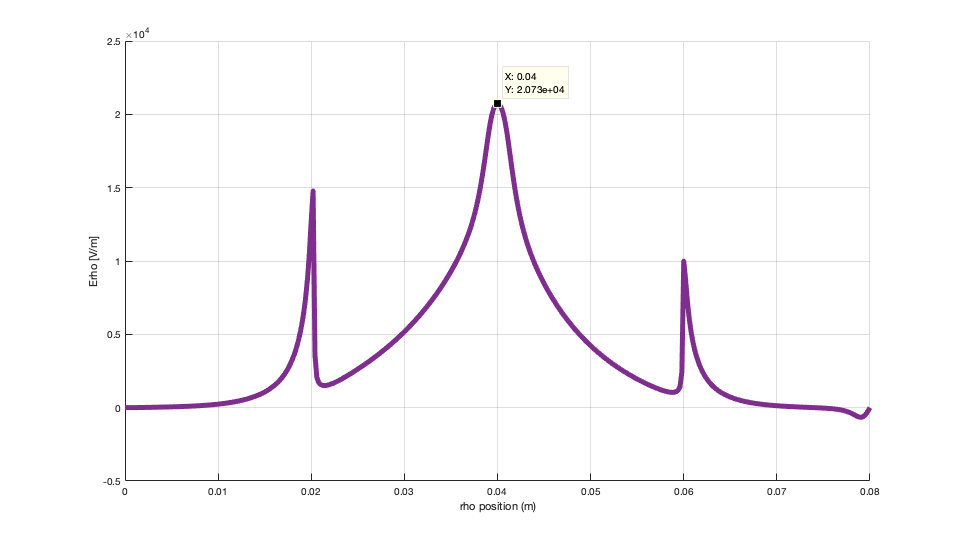
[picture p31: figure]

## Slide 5

Electric field estimate (transverse field)

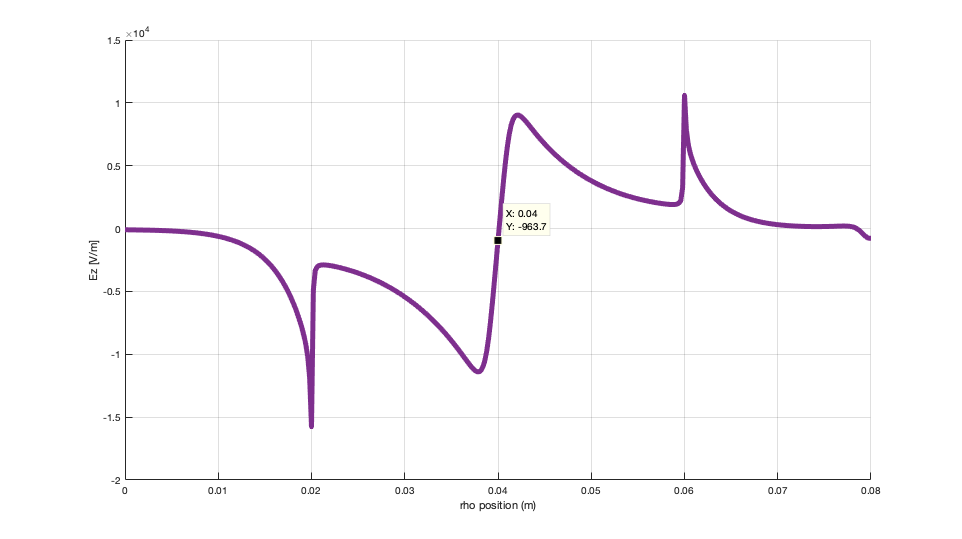
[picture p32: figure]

## Model Estimate

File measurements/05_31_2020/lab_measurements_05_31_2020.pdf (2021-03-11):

## Lab Measurements

Starting meas
OLG dB : 23
OLG deg : 24

Locked Error signal (Post fss) spectra : 25

Fss tfs
600 mV excitation:
Db: 26
Deg: 27
1 V excitation:
Db: 28
Deg: 29
200 mV excitation:
Db: 30
Deg: 31
100 mV excitation:
Db: 32
Deg: 33
300 mV excitation (1hz-30kHz): Db: 42
Deg: 43
300 mV excitation (1hz-102.4kHz): Db: 44
Deg: 45

HVA tfs:
Removed unused t

Amplitude knob less than halfway (37.5% of max): 128Hz-100kHz (200 points) :
Db: 34
Deg: 35
1Hz -50kHz (200 points):
Db: 36
Deg: 37

1Hz-10kHz(200 points):
Db: 38
Deg: 39
1hz-102.4khz no pomona (300 points) Db: 40
Deg: 41

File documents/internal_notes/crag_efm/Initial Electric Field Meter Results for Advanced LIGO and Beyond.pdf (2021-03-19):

# Initial Electric Field Meter Results for Advanced LIGO and Beyond

## Craig Cahillane June 18, 2018

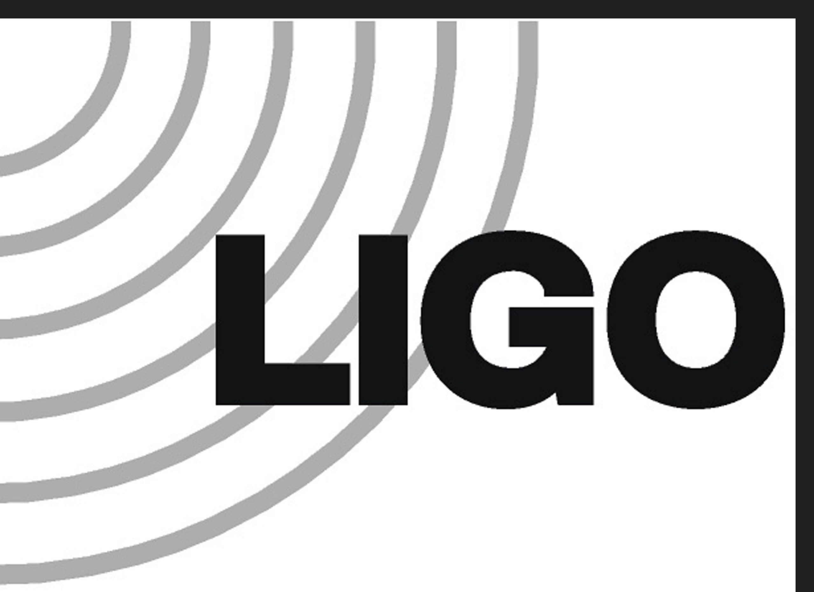
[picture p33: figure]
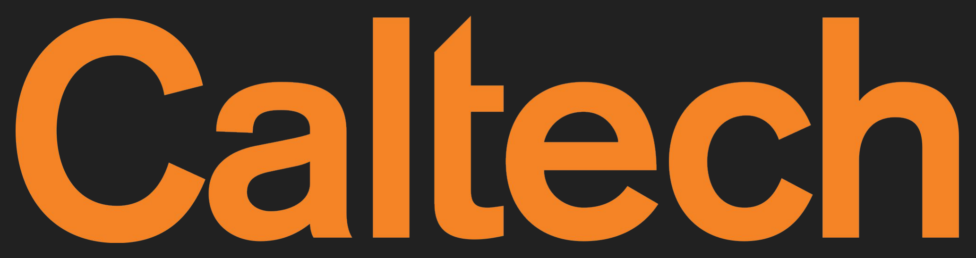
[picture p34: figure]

## Table of Contents

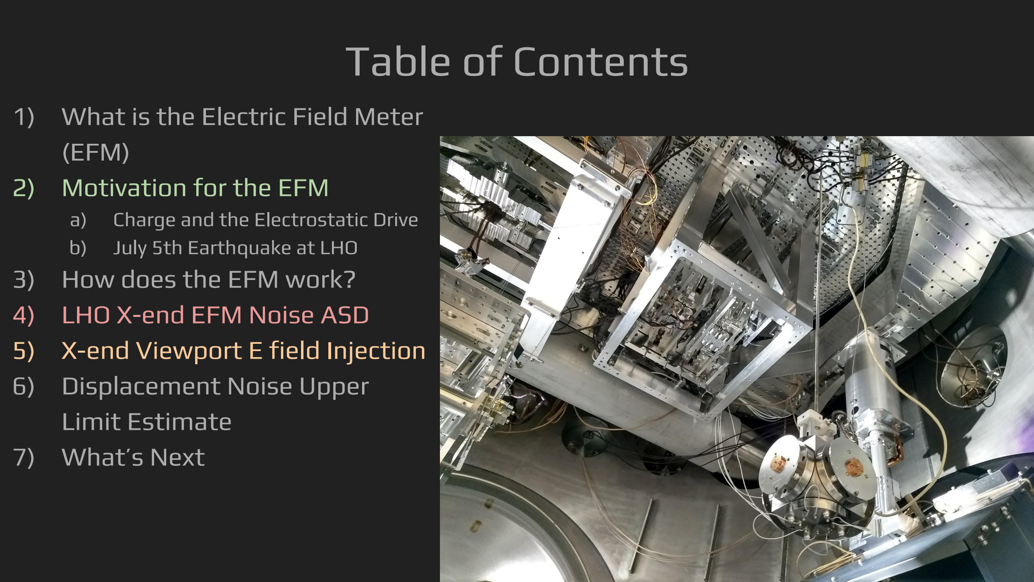
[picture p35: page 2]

1) What is the Electric Field Meter (EFM)
2) Motivation for the EFM
a) Charge and the Electrostatic Drive
b) July 5th Earthquake at LHO
3) How does the EFM work?
4) LHO X-end EFM Noise ASD
5) X-end Viewport E field Injection
6) Displacement Noise Upper Limit Estimate
7) What’s Next

## What is the Electric Field Meter?

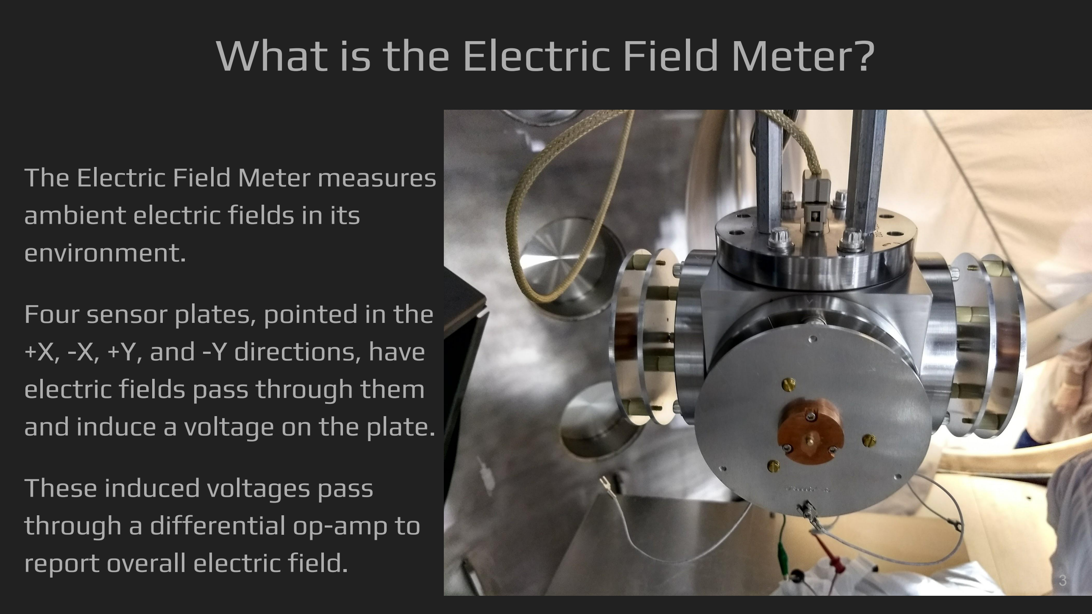
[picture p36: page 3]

The Electric Field Meter measures ambient electric fields in its environment.

Four sensor plates, pointed in the +X, -X, +Y, and -Y directions, have electric fields pass through them and induce a voltage on the plate.

These induced voltages pass through a differential op-amp to report overall electric field.

## Motivation for the Electric Field Meter

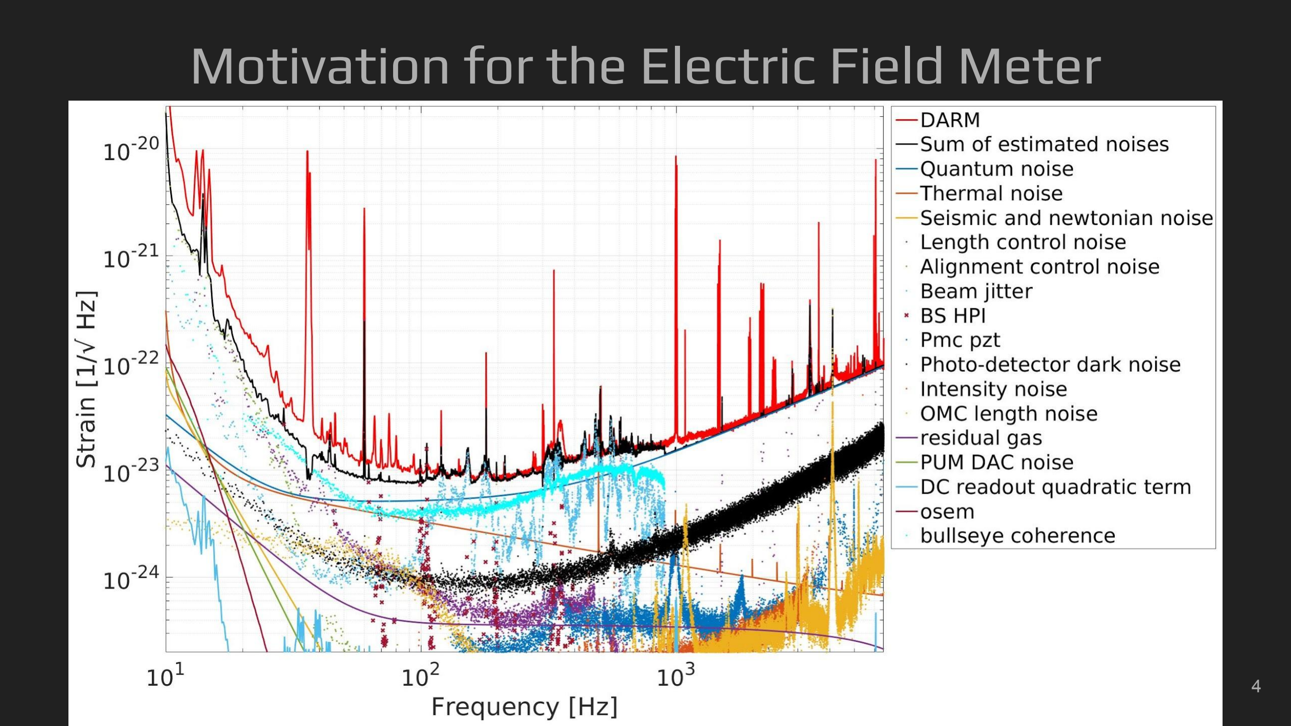
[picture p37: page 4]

## Charge and The Electrostatic Drive (ESD)

The Electrostatic Drive (ESD) polarizes the optic in order to actuate upon it, creating a small surface charge density.

Optics made of fused silica, an insulator. Difficult for charges to move around, makes discharging optics hard.

Ion pumps produce UV/X-rays
which ionize test mass directly.
First Contact, earthquake stops

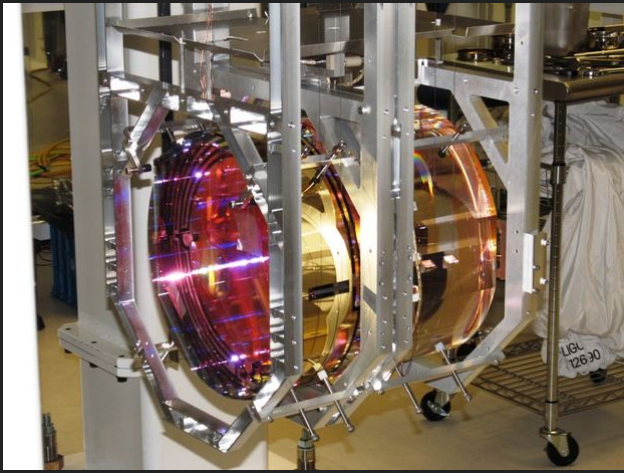
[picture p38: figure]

also sources of charge. | 5

## Three ways Electric Fields interact with the ETM

Net Charge (F ~ Q*E ~ f⁻²); Dielectric Polarization (F ~ E²; Space Charge Polarization (aka charge hopping or charge fluctuations) (F ~ f⁻³); Test Mass Q

## July 5th, 2017 Earthquake at LHO


## July 5th, 2017 Earthquake

A 5.8 magnitude earthquake hit western Montana, around 300 miles from Hanford, during O2. This caused a 25% loss in sensitive range at Hanford.


July 5th
Earthquake

## July 5th, 2017 Earthquake


A 5.8 magnitude earthquake hit western Montana, around 300 miles from Hanford, during O2.

The core optics hit the earthquake stops, which transferred charge from the stops to the optics.

Discharging reduced noise, but could not eliminate all noise.

## How does the Electric Field Meter work?

Some electric field is incident on the EFM.

EFM Body (Grounded); Sensor Pin

The field terminates on the grounded body, and passes
through the floating sensor plates, inducing voltage

Inside the EFM is a differential op-amp circuit, so the EFM output is

## Calibrating the Electric Field Meter

plates; and the sensor plate; EFM Body (Grounded); Sensor Pin; Cal Plate; Sensor Plate

Attach a floating calibration plate
and drive it using an SR785.

Measure transfer function from
driven to output voltage.

Measure the capacitances
between the cal and sensor
and the EFM body

Estimate calibration volts to
electric field transfer function

## Calibrating the Electric Field Meter


## LHO X-end Electric Field Meter Noise ASD


## X-end Viewport Electric Field Injection


During O1, Robert Schofield injected an electric field at 211 Hz through an X-end viewport to measure the coupling to DARM.

After installing the 2nd EFM prototype, Robert and Georgia repeated the measurement. (https://alog.ligo-wa.caltech.edu/aLOG/index.php?callRep=41589)

SNR for the EFM is greater.
For O3 we’ll be sensitive to electric fields coupling into DARM

## What’s Next

1) Install EFMs at LHO Y-end and LLO.
2) Figure out whether the EFM is sensitive enough to tell us interesting info about electric fields.
3) Better estimate of electric field to length coupling.
4) Think about potential sources of excess in-chamber electric fields.
5) Estimate the EFM electric field to ETM electric field transfer function. (Hard)
6) If it is, we can answer big questions:
a) How much do stray E fields couple to DARM?
b) Can we do something to limit the stray E field levels?
c) Are ESDs with fused silica ETMs viable actuators for the future of low-noise interferometry?

## EFM Team

Rai Weiss, Peter Fritschel


Rich Abbott, Calum Torrie, Luis Sanchez


Georgia Mansell, Jeff Kissel, Robert Schofield, Craig Cahillane


Carl Adams, Carl Blair

## Bibliography

[1] Weiss, R. “Note on Electrostatics in the LIGO Suspensions.” https://dcc.ligo.org/T960137
[2] Koptsov D.V.,Prokhorov L.G., Mitrofanov V.P. “Measurement of fluctuations of electrostatic force acting between a dielectric plate and an electrostatic drive.” https://dcc.ligo.org/P1600344
[3] Martynov, D. “Lock Acquisition and Sensitivity Analysis of Advanced LIGO Interferometers.” Thesis. https://dcc.ligo.org/P1500087
[4] Dwyer, S. “Some plots showing charge noise which appeared after July EQ.” LHO alog 38854. https://alog.ligo-wa.caltech.edu/aLOG/index.php?callRep=38854
[5] Prokhorov, L.G. and Kissel, J. “Actuation force of the ESD with charges and cage effects.” https://dcc.ligo.org/T1500467
[6] Weiss, R. “Notes on the Electric Field Meter version 3” https://dcc.ligo.org/T1700569
[7] Prokhorov, L.G. “Interaction of the ESD with electrical charges of the test masses in Advanced LIGO.” https://dcc.ligo.org/G1600751
[8] Sorazu, B. “Charging issues at the sites” https://dcc.ligo.org/G1401033
[9] Lantz, B. and Mason, K. “Overview for the Advanced LIGO HAM ISI Preliminary Design Review” https://dcc.ligo.org/T080236
[10] aLIGO Quad Assembly. https://dcc.ligo.org/LIGO-D060454

## Extra Slides

## EFM Volts ASD


## Electric Field Displacement Noise Estimate


## EFM LHO aLOGs

Characterization and EF Injection for 1st EFM Prototype: https://alog.ligo-wa.caltech.edu/aLOG/index.php?callRep=40878 Initial Calibration of 1st EFM Prototype: https://alog.ligo-wa.caltech.edu/aLOG/index.php?callRep=40949
Optics Lab Characterization of 2nd Prototype EFM: https://alog.ligo-wa.caltech.edu/aLOG/index.php?callRep=41374
EFM CDS Channels added to PEM: https://alog.ligo-wa.caltech.edu/aLOG/index.php?callRep=41393
Installation of 2nd Prototype: https://alog.ligo-wa.caltech.edu/aLOG/index.php?callRep=41427
Characterization of 2nd Prototype: https://alog.ligo-wa.caltech.edu/aLOG/index.php?callRep=41483
Further Characterization of 2nd Prototype: https://alog.ligo-wa.caltech.edu/aLOG/index.php?callRep=41532 Electric Field Injection with 2nd Prototype: https://alog.ligo-wa.caltech.edu/aLOG/index.php?callRep=41559 Electric Field Injection Results: https://alog.ligo-wa.caltech.edu/aLOG/index.php?callRep=41589 Installation of EFM1: https://alog.ligo-wa.caltech.edu/aLOG/index.php?callRep=42245
Characterization of EFM1: https://alog.ligo-wa.caltech.edu/aLOG/index.php?callRep=42250

Note: 1st EFM Prototype is Rai Weiss’s 3rd version which was sent to LHO for initial tests.
The 2nd EFM Prototype is the first version build by Rich Abbott, Calum Torrie, and Luis Sanchez at Caltech. EFM1 is the permanently installed version at LHO X-end)

## Initial Prototype Electric Field Meter


Rai Weiss’s Prototype, installed briefly at LHO by Georgia Mansell and Jeff Kissel

Was put in chamber, characterized, and detected the ISI drive electric fields.

Results were deemed promising enough to have Rich Abbott and Calum Torrie design a more permanent EFM for use during O3.

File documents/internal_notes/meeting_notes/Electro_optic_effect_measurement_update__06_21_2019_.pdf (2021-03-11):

## Piezoelectric effect measurement update (Noise and initial design considerations)

Ari Pedersen, Danny Vander-Hyde

Syracuse University

June 21, 2019

## Overview

1 | How big is the Piezoelectric effect?
2 | Competing with laser frequency noise
3 | Electrode / Sample mount

## Some preliminary figures

According to Marty Fejer ∂φ
∂E ≈ 4.5 ∗ 10⁻¹⁰ m
V
Conservatively we can attempt to create a setup that would generate Electric fields on the order of 10 V / 2.5 cm = 400 V/m
This would lead to an effect of 1.8 ∗ 10⁻⁷

[rad] or 3.05 ∗ 10⁻¹⁴[m]

This is for a single layer so we could multiply by the number of AlGaAs layers? (Maybe increases the effect by an order of magnitude?)

## Light source: Mephisto 2000 NE


## Frequency noise to phase noise

Assuming that the largest laser frequency fluctuations (∆flaser) 11,500 Hz away from the carrier frequency. Can calculate this as phase noise ∆flaser
flaser

on the order of 4.08 ∗ 10⁻¹¹ [rad]

If we are to use a simple Fabry-Perot cavity to measure this effect, we would need:
∆flaser

flaser

<

∆Lcav

Lcav

Where I am considering ∆Lcav to be the induced length change due to the piezoelectric effect.

Assuming we have a 10 cm length cavity we can estimate
3.05∗10⁻¹⁴
.01 = 3.05 ∗ 10⁻¹² [rad] which lies an order of magnitude below the effect we wish to measure. :(

Can modulate the electric field at some higher frequency where the frequency noise is less of an issue (how fast can we modulate the field and still notice the effect? → Impulse / Step response analysis)

## PDH locking

First attempt to suppress laser frequency noise while keeping simple cavity design in mind.
Black states (ref) (https://youtu.be/tX884B8GrEE) that a closed loop PDH system can suppress frequency noise (n) below the reference cavity pole frequency by a factor of
1
1 + H(s) ∗ D(s) ∗ K(s)

Where H(s) [Hz/V] is the laser transfer function, D(s) [V/Hz] is the PDH transfer function, and K(s) is the servo gain.

Dont have exact values to propose but this could be a place to start. Propose we use the LIGO PMC we have on the AMM table as refrence cavity. (Might want to double check how destructive this could be to phase camera peeps)

If this does not provide enough suppression, we might have to move on to an interferometer design.

## Electrode design

Am thinking of machining a thin square aluminum plate significantly larger than the size of the optic so to avoid field fringe effects. (Might need to do some quick calculations to establish the minimum size of this plate)

Will also want to drill a hole in the center of the plate so to allow the beam to pass through to the AlGaAs sample without introducing any spatial defects to the intra-cavity beam. (Can do some calculations for optimal aperture size)

## Sample / electrode mount(s)

Traditional metallic optic mounts could introduce unwanted charge distributions. Need to think of ways around this. Here are some inital thoughts:

In-air
3D printed flexure optic mount
Could potentially be a simple one piece print

In-vacuum
Monolithic fused silica holder (Work on 3d printed concept? request to have made at Corning?)

Dont know how we would embed a fused silica holder in vacuum (suspended?) (clamped on table?)

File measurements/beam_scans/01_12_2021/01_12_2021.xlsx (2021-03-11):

Beam scan (01-12-2021) |  | After iris 1 along eo path wrt last steering mirror before entering cavity
z (inches) | x diameter (\mu m) | y diamter (\mu m)
8 | 712 | 986.5
9 | 663.2 | 832.9
10 | 579.8 | 721.3
17 | 450.7 | 240.8
18 | 476.3 | 261.9
19 | 485.3 | 316.6
20 | 485.4 | 377.2
21 | 499.1 | 505.1

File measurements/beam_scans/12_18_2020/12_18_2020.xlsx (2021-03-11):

Beam scan (10-24-2019) |  | After iris 1 along eo path wrt last steering mirror before entering cavity
z (inches) | x diameter (\mu m) | y diamter (\mu m)
8 | 663.3 | 355.3
9 | 614.5 | 374.9
10 | 548 | 383.1
11 | 504.9 | 464.8
17 | 483 | 964
18 | 477.7 | 1046.7
19 | 517.1 | 1123.5
20 | 557.5 | 1183.7
21 | 597.1 | 1264.8

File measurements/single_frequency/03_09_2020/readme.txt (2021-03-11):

09-03-2020 measurements

VRMS/sqrt(hz)
Windowing
Uniform  - 872
Flattop - 873
Hanning - 874
BMH - 875
Kaiser - 876
Force/exp - 877
 
VPK
Uniform - 878
Flattop - 879
Hanning - 881 
BMH - 882
Kaiser - 883
Force / exp - 884
Another flattop attempt - 885

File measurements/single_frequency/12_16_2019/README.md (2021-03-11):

SCRN0012 and SCRN0013 were taken by stefan. It is the error signal spectra (while locked) measured at the SR560 configured for unity gain (treated as a summer). One of them is measured at the input while the other is the output.

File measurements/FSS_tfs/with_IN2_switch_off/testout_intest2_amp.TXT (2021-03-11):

+1.000000e+000	   -4.398355e+001
+1.059686e+000	   -4.449379e+001
+1.122935e+000	   -4.496461e+001
+1.189959e+000	   -4.547662e+001
+1.260984e+000	   -4.595878e+001
+1.336248e+000	   -4.646425e+001
+1.416003e+000	   -4.697712e+001
+1.500520e+000	   -4.743069e+001
+1.590080e+000	   -4.793587e+001
+1.684987e+000	   -4.844496e+001
+1.785558e+000	   -4.890898e+001
+1.892131e+000	   -4.943468e+001
+2.005066e+000	   -4.990738e+001
+2.124741e+000	   -5.041360e+001
+2.251559e+000	   -5.093852e+001
+2.385947e+000	   -5.135565e+001
+2.528356e+000	   -5.185077e+001
+2.679264e+000	   -5.236310e+001
+2.839180e+000	   -5.291580e+001
+3.008641e+000	   -5.333287e+001
+3.188216e+000	   -5.378271e+001
+3.378509e+000	   -5.439374e+001
+3.580161e+000	   -5.477616e+001
+3.793848e+000	   -5.528054e+001
+4.020289e+000	   -5.569960e+001
+4.260246e+000	   -5.625211e+001
+4.514525e+000	   -5.678593e+001
+4.783981e+000	   -5.721019e+001
+5.069520e+000	   -5.777507e+001
+5.372102e+000	   -5.816255e+001
+5.692743e+000	   -5.855659e+001
+6.032523e+000	   -5.904639e+001
+6.392583e+000	   -5.954645e+001
+6.774134e+000	   -5.993636e+001
+7.178458e+000	   -6.060156e+001
+7.606915e+000	   -6.084221e+001
+8.060945e+000	   -6.135269e+001
+8.542073e+000	   -6.165347e+001
+9.051920e+000	   -6.226231e+001
+9.592196e+000	   -6.250629e+001
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

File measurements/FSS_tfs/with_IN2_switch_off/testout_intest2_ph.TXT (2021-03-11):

+1.000000e+000	   -8.354916e+001
+1.059686e+000	   -8.403613e+001
+1.122935e+000	   -8.446671e+001
+1.189959e+000	   -8.537281e+001
+1.260984e+000	   -8.625072e+001
+1.336248e+000	   -8.641776e+001
+1.416003e+000	   -8.728412e+001
+1.500520e+000	   -8.800471e+001
+1.590080e+000	   -8.850889e+001
+1.684987e+000	   -8.919505e+001
+1.785558e+000	   -9.002379e+001
+1.892131e+000	   -9.039083e+001
+2.005066e+000	   -9.064410e+001
+2.124741e+000	   -9.175029e+001
+2.251559e+000	   -9.223328e+001
+2.385947e+000	   -9.318168e+001
+2.528356e+000	   -9.398214e+001
+2.679264e+000	   -9.410221e+001
+2.839180e+000	   -9.528209e+001
+3.008641e+000	   -9.524311e+001
+3.188216e+000	   -9.620854e+001
+3.378509e+000	   -9.691319e+001
+3.580161e+000	   -9.790131e+001
+3.793848e+000	   -9.829209e+001
+4.020289e+000	   -9.970664e+001
+4.260246e+000	   -1.008683e+002
+4.514525e+000	   -1.017460e+002
+4.783981e+000	   -1.018656e+002
+5.069520e+000	   -1.028893e+002
+5.372102e+000	   -1.040419e+002
+5.692743e+000	   -1.043638e+002
+6.032523e+000	   -1.061710e+002
+6.392583e+000	   -1.066370e+002
+6.774134e+000	   -1.079709e+002
+7.178458e+000	   -1.086030e+002
+7.606915e+000	   -1.102856e+002
+8.060945e+000	   -1.123368e+002
+8.542073e+000	   -1.132585e+002
+9.051920e+000	   -1.147418e+002
+9.592196e+000	   -1.165485e+002
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

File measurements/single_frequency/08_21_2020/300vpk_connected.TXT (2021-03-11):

+1.280000e+002	   +4.021280e-001
+2.560000e+002	   +1.188332e-001
+3.840000e+002	   +1.528812e-002
+5.120000e+002	   +1.506301e-002
+6.400000e+002	   +2.104686e-002
+7.680000e+002	   +3.267416e-002
+8.960000e+002	   +3.663668e-002
+1.024000e+003	   +2.515295e-002
+1.152000e+003	   +1.385041e-002
+1.280000e+003	   +8.664332e-003
+1.408000e+003	   +6.066740e-003
+1.536000e+003	   +4.168599e-003
+1.664000e+003	   +3.173807e-003
+1.792000e+003	   +2.904511e-003
+1.920000e+003	   +2.887768e-003
+2.048000e+003	   +3.060779e-003
+2.176000e+003	   +3.123968e-003
+2.304000e+003	   +3.116219e-003
+2.432000e+003	   +2.861060e-003
+2.560000e+003	   +2.519979e-003
+2.688000e+003	   +2.480646e-003
+2.816000e+003	   +2.160851e-003
+2.944000e+003	   +1.685734e-003
+3.072000e+003	   +1.561878e-003
+3.200000e+003	   +1.741088e-003
+3.328000e+003	   +1.629148e-003
+3.456000e+003	   +1.293690e-003
+3.584000e+003	   +1.177858e-003
+3.712000e+003	   +1.166914e-003
+3.840000e+003	   +1.140012e-003
+3.968000e+003	   +1.106176e-003
+4.096000e+003	   +1.090613e-003
+4.224000e+003	   +1.055409e-003
+4.352000e+003	   +1.012755e-003
+4.480000e+003	   +9.971001e-004
+4.608000e+003	   +9.681270e-004
+4.736000e+003	   +9.492430e-004
+4.864000e+003	   +9.441514e-004
+4.992000e+003	   +9.410657e-004
+5.120000e+003	   +9.189975e-004
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

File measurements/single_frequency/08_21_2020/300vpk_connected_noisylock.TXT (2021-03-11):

+1.280000e+002	   +3.952068e-001
+2.560000e+002	   +1.163795e-001
+3.840000e+002	   +1.551802e-002
+5.120000e+002	   +1.560644e-002
+6.400000e+002	   +2.071391e-002
+7.680000e+002	   +3.120156e-002
+8.960000e+002	   +3.580907e-002
+1.024000e+003	   +2.549807e-002
+1.152000e+003	   +1.425810e-002
+1.280000e+003	   +8.523628e-003
+1.408000e+003	   +5.687747e-003
+1.536000e+003	   +3.958523e-003
+1.664000e+003	   +2.998751e-003
+1.792000e+003	   +2.700141e-003
+1.920000e+003	   +2.702653e-003
+2.048000e+003	   +2.940825e-003
+2.176000e+003	   +3.132149e-003
+2.304000e+003	   +3.244067e-003
+2.432000e+003	   +2.902976e-003
+2.560000e+003	   +2.387819e-003
+2.688000e+003	   +2.388394e-003
+2.816000e+003	   +2.081062e-003
+2.944000e+003	   +1.467132e-003
+3.072000e+003	   +1.353038e-003
+3.200000e+003	   +1.740972e-003
+3.328000e+003	   +1.557726e-003
+3.456000e+003	   +8.996260e-004
+3.584000e+003	   +5.935907e-004
+3.712000e+003	   +6.228563e-004
+3.840000e+003	   +6.360033e-004
+3.968000e+003	   +5.812192e-004
+4.096000e+003	   +5.267214e-004
+4.224000e+003	   +5.156184e-004
+4.352000e+003	   +5.455814e-004
+4.480000e+003	   +5.248464e-004
+4.608000e+003	   +4.499682e-004
+4.736000e+003	   +3.939883e-004
+4.864000e+003	   +3.753057e-004
+4.992000e+003	   +3.674576e-004
+5.120000e+003	   +3.672705e-004
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

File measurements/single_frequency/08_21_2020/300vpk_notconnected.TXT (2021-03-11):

+1.280000e+002	   +2.784982e-001
+2.560000e+002	   +8.367085e-002
+3.840000e+002	   +1.369460e-002
+5.120000e+002	   +1.507218e-002
+6.400000e+002	   +2.046022e-002
+7.680000e+002	   +3.086910e-002
+8.960000e+002	   +3.510400e-002
+1.024000e+003	   +2.503563e-002
+1.152000e+003	   +1.386526e-002
+1.280000e+003	   +8.285268e-003
+1.408000e+003	   +5.785613e-003
+1.536000e+003	   +4.085529e-003
+1.664000e+003	   +3.129868e-003
+1.792000e+003	   +2.851176e-003
+1.920000e+003	   +2.811847e-003
+2.048000e+003	   +2.995500e-003
+2.176000e+003	   +3.036691e-003
+2.304000e+003	   +2.971905e-003
+2.432000e+003	   +2.741694e-003
+2.560000e+003	   +2.454323e-003
+2.688000e+003	   +2.419853e-003
+2.816000e+003	   +2.150896e-003
+2.944000e+003	   +1.710152e-003
+3.072000e+003	   +1.542540e-003
+3.200000e+003	   +1.685875e-003
+3.328000e+003	   +1.575043e-003
+3.456000e+003	   +1.256000e-003
+3.584000e+003	   +1.125649e-003
+3.712000e+003	   +1.126190e-003
+3.840000e+003	   +1.147062e-003
+3.968000e+003	   +1.134979e-003
+4.096000e+003	   +1.114296e-003
+4.224000e+003	   +1.084658e-003
+4.352000e+003	   +1.085415e-003
+4.480000e+003	   +1.073186e-003
+4.608000e+003	   +1.014390e-003
+4.736000e+003	   +9.794704e-004
+4.864000e+003	   +9.506422e-004
+4.992000e+003	   +9.292376e-004
+5.120000e+003	   +9.039975e-004
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

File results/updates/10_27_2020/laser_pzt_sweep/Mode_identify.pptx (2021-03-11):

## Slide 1


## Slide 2


FSR

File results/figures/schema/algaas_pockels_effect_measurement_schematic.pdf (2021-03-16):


! " $#

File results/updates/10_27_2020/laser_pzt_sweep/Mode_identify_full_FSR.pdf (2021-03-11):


FSR


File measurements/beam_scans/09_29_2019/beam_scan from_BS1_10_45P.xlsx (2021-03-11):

z (in) | W_x (\mu m) | W_y (\mu m)
11.4 | 548.7 | 480.8
12.4 | 504.9 | 436.9
13.4 | 446 | 401.3
14.4 | 393.3 | 364
15.4 | 380.3 | 377.8
16.4 | 373.8 | 417.1
17.4 | 374.8 | 449.6
18.4 | 362 | 483.9
19.4 | 412 | 537.7
20.4 | 471.5 | 603.2
21.4 | 537 | 670.1
22.4 | 614.2 | 738.1
23.4 | 696.8 | 812.7
24.4 | 768.9 | 888.7
25.4 | 845 | 938.4
26.4 | 914.3 | 1016.9
REMEMBER IT RECORDS DIAMETER

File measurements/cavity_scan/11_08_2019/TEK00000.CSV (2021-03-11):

TIME | CH2 | CH3
-9.6200e-03 | 0.098 | 0.424
-9.6190e-03 | 0.096 | 0.424
-9.6180e-03 | 0.1 | 0.428
-9.6170e-03 | 0.092 | 0.44
-9.6160e-03 | 0.092 | 0.424
-9.6150e-03 | 0.096 | 0.436
-9.6140e-03 | 0.092 | 0.432
-9.6130e-03 | 0.098 | 0.436
-9.6120e-03 | 0.096 | 0.436
-9.6110e-03 | 0.094 | 0.44
-9.6100e-03 | 0.09 | 0.432
-9.6090e-03 | 0.088 | 0.436
-9.6080e-03 | 0.092 | 0.428
-9.6070e-03 | 0.094 | 0.44
-9.6060e-03 | 0.094 | 0.428
-9.6050e-03 | 0.092 | 0.432
-9.6040e-03 | 0.086 | 0.424
-9.6030e-03 | 0.092 | 0.428
-9.6020e-03 | 0.098 | 0.424
-9.6010e-03 | 0.096 | 0.436
-9.6000e-03 | 0.098 | 0.432
-9.5990e-03 | 0.092 | 0.432
-9.5980e-03 | 0.088 | 0.428
-9.5970e-03 | 0.092 | 0.432
-9.5960e-03 | 0.094 | 0.436
-9.5950e-03 | 0.092 | 0.436
-9.5940e-03 | 0.09 | 0.436
-9.5930e-03 | 0.092 | 0.432
-9.5920e-03 | 0.094 | 0.432
-9.5910e-03 | 0.094 | 0.432
-9.5900e-03 | 0.092 | 0.432
-9.5890e-03 | 0.088 | 0.432
-9.5880e-03 | 0.094 | 0.44
-9.5870e-03 | 0.09 | 0.424
-9.5860e-03 | 0.092 | 0.432
-9.5850e-03 | 0.098 | 0.444
-9.5840e-03 | 0.096 | 0.44
-9.5830e-03 | 0.094 | 0.432
-9.5820e-03 | 0.092 | 0.444
-9.5810e-03 | 0.098 | 0.44
-9.5800e-03 | 0.094 | 0.432
-9.5790e-03 | 0.092 | 0.432
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

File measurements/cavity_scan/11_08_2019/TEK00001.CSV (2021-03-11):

TIME | CH1 | CH2 | CH3
-9.6200e-03 | -0.246 | 0.098 | 0.436
-9.6190e-03 | -0.246 | 0.094 | 0.428
-9.6180e-03 | -0.246 | 0.098 | 0.436
-9.6170e-03 | -0.246 | 0.096 | 0.432
-9.6160e-03 | -0.246 | 0.098 | 0.436
-9.6150e-03 | -0.246 | 0.092 | 0.436
-9.6140e-03 | -0.246 | 0.102 | 0.444
-9.6130e-03 | -0.246 | 0.096 | 0.436
-9.6120e-03 | -0.246 | 0.096 | 0.432
-9.6110e-03 | -0.246 | 0.096 | 0.44
-9.6100e-03 | -0.246 | 0.096 | 0.44
-9.6090e-03 | -0.246 | 0.098 | 0.436
-9.6080e-03 | -0.246 | 0.1 | 0.432
-9.6070e-03 | -0.246 | 0.096 | 0.436
-9.6060e-03 | -0.246 | 0.092 | 0.436
-9.6050e-03 | -0.246 | 0.094 | 0.428
-9.6040e-03 | -0.246 | 0.092 | 0.444
-9.6030e-03 | -0.246 | 0.098 | 0.432
-9.6020e-03 | -0.246 | 0.094 | 0.436
-9.6010e-03 | -0.246 | 0.092 | 0.432
-9.6000e-03 | -0.246 | 0.096 | 0.444
-9.5990e-03 | -0.246 | 0.092 | 0.428
-9.5980e-03 | -0.246 | 0.098 | 0.444
-9.5970e-03 | -0.246 | 0.094 | 0.444
-9.5960e-03 | -0.246 | 0.104 | 0.444
-9.5950e-03 | -0.246 | 0.098 | 0.436
-9.5940e-03 | -0.246 | 0.096 | 0.444
-9.5930e-03 | -0.246 | 0.098 | 0.436
-9.5920e-03 | -0.246 | 0.098 | 0.432
-9.5910e-03 | -0.246 | 0.088 | 0.436
-9.5900e-03 | -0.246 | 0.094 | 0.432
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

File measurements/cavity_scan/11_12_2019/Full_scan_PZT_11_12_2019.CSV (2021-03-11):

TIME | CH2 | CH3 | CH4
-1.9600e-02 | -0.116 | 0.0014 | 0.86
-1.9596e-02 | -0.12 | 0.0008 | 0.84
-1.9592e-02 | -0.12 | -2.84217e-18 | 0.82
-1.9588e-02 | -0.128 | 0.0006 | 0.86
-1.9584e-02 | -0.124 | 0.0018 | 0.88
-1.9580e-02 | -0.12 | 0.001 | 0.86
-1.9576e-02 | -0.12 | 0.0016 | 0.88
-1.9572e-02 | -0.12 | 0.0016 | 0.84
-1.9568e-02 | -0.116 | 0.0006 | 0.84
-1.9564e-02 | -0.12 | 0.0014 | 0.82
-1.9560e-02 | -0.124 | 0.001 | 0.84
-1.9556e-02 | -0.112 | 0.0004 | 0.84
-1.9552e-02 | -0.124 | 0.0006 | 0.88
-1.9548e-02 | -0.128 | 0.0008 | 0.9
-1.9544e-02 | -0.124 | 0.0006 | 0.84
-1.9540e-02 | -0.132 | 0.0004 | 0.92
-1.9536e-02 | -0.12 | 0.0006 | 0.84
-1.9532e-02 | -0.124 | 0.0004 | 0.84
-1.9528e-02 | -0.132 | 0.001 | 0.9
-1.9524e-02 | -0.128 | 0.0008 | 0.86
-1.9520e-02 | -0.124 | 0.0012 | 0.88
-1.9516e-02 | -0.12 | 0.0018 | 0.94
-1.9512e-02 | -0.12 | 0.0012 | 0.86
-1.9508e-02 | -0.112 | 0.0008 | 0.84
-1.9504e-02 | -0.124 | 0.0004 | 0.86
-1.9500e-02 | -0.124 | 0.0006 | 0.84
-1.9496e-02 | -0.12 | 0.0012 | 0.88
-1.9492e-02 | -0.124 | 0.0014 | 0.84
-1.9488e-02 | -0.124 | 0.0004 | 0.88
-1.9484e-02 | -0.128 | 0.0008 | 0.86
-1.9480e-02 | -0.12 | 0.0012 | 0.84
-1.9476e-02 | -0.128 | 0.0008 | 0.82
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

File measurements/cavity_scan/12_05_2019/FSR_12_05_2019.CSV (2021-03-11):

TIME | CH3 | CH4
-6.9600e-02 | 0.014 | 0.042
-6.9590e-02 | 0.01 | 0.036
-6.9580e-02 | 0.02 | 0.044
-6.9570e-02 | 0.006 | 0.042
-6.9560e-02 | 0.012 | 0.044
-6.9550e-02 | 0.016 | 0.042
-6.9540e-02 | 0.014 | 0.046
-6.9530e-02 | 0.018 | 0.038
-6.9520e-02 | 0.014 | 0.04
-6.9510e-02 | 0.012 | 0.036
-6.9500e-02 | 0.016 | 0.04
-6.9490e-02 | 0.012 | 0.042
-6.9480e-02 | 0.018 | 0.04
-6.9470e-02 | 0.012 | 0.04
-6.9460e-02 | 0.012 | 0.04
-6.9450e-02 | 0.012 | 0.042
-6.9440e-02 | 0.016 | 0.046
-6.9430e-02 | 0.008 | 0.04
-6.9420e-02 | 0.014 | 0.036
-6.9410e-02 | 0.014 | 0.036
-6.9400e-02 | 0.016 | 0.046
-6.9390e-02 | 0.018 | 0.038
-6.9380e-02 | 0.014 | 0.038
-6.9370e-02 | 0.014 | 0.044
-6.9360e-02 | 0.016 | 0.042
-6.9350e-02 | 0.018 | 0.042
-6.9340e-02 | 0.01 | 0.034
-6.9330e-02 | 0.012 | 0.04
-6.9320e-02 | 0.008 | 0.04
-6.9310e-02 | 0.014 | 0.034
-6.9300e-02 | 0.016 | 0.04
-6.9290e-02 | 0.016 | 0.034
-6.9280e-02 | 0.012 | 0.044
-6.9270e-02 | 0.014 | 0.044
-6.9260e-02 | 0.016 | 0.044
-6.9250e-02 | 0.02 | 0.038
-6.9240e-02 | 0.006 | 0.032
-6.9230e-02 | 0.014 | 0.036
-6.9220e-02 | 0.02 | 0.04
-6.9210e-02 | 0.012 | 0.036
-6.9200e-02 | 0.012 | 0.038
-6.9190e-02 | 0.018 | 0.036
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

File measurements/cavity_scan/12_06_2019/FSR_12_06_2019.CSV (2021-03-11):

TIME | CH3 | CH4
-6.9600e-02 | 0.004 | 0.152
-6.9590e-02 | 0.016 | 0.154
-6.9580e-02 | 0.004 | 0.152
-6.9570e-02 | 0.004 | 0.152
-6.9560e-02 | 0.004 | 0.15
-6.9550e-02 | 0.012 | 0.148
-6.9540e-02 | -5.68434e-17 | 0.154
-6.9530e-02 | 0.008 | 0.148
-6.9520e-02 | 0.016 | 0.15
-6.9510e-02 | 0.008 | 0.152
-6.9500e-02 | 0.012 | 0.15
-6.9490e-02 | 0.012 | 0.142
-6.9480e-02 | 0.008 | 0.146
-6.9470e-02 | 0.008 | 0.148
-6.9460e-02 | -5.68434e-17 | 0.15
-6.9450e-02 | 0.02 | 0.152
-6.9440e-02 | 0.008 | 0.148
-6.9430e-02 | 0.016 | 0.15
-6.9420e-02 | 0.012 | 0.146
-6.9410e-02 | 0.016 | 0.146
-6.9400e-02 | 0.008 | 0.144
-6.9390e-02 | 0.016 | 0.148
-6.9380e-02 | 0.004 | 0.148
-6.9370e-02 | 0.004 | 0.154
-6.9360e-02 | 0.004 | 0.144
-6.9350e-02 | 0.008 | 0.154
-6.9340e-02 | 0.012 | 0.144
-6.9330e-02 | 0.008 | 0.152
-6.9320e-02 | 0.008 | 0.154
-6.9310e-02 | 0.012 | 0.15
-6.9300e-02 | 0.004 | 0.154
-6.9290e-02 | 0.004 | 0.148
-6.9280e-02 | 0.02 | 0.148
-6.9270e-02 | 0.016 | 0.148
-6.9260e-02 | 0.012 | 0.146
-6.9250e-02 | 0.016 | 0.146
-6.9240e-02 | 0.016 | 0.148
-6.9230e-02 | 0.008 | 0.15
-6.9220e-02 | 0.02 | 0.142
-6.9210e-02 | 0.008 | 0.148
-6.9200e-02 | 0.012 | 0.142
-6.9190e-02 | 0.008 | 0.148
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

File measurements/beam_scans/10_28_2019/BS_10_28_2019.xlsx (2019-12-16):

Beam scan (10-28-2019) |  | This scan is wrt first iris after SM5*
z (inches) | x diameter (\mu m) | y diamter (\mu m)
1 | 840.7 | 1558.9
2 | 766.8 | 1338.2
3 | 714.8 | 1200.6
4 | 680.7 | 1047.2
5 | 624.8 | 909.5
6 | 594.7 | 763.3
7 | 554.4 | 625.6
8 | 514.9 | 487.4
9 | 475.4 | 386.2
10 | 462.7 | 284.1
11 | 422 | 200.3
12 | 403.4 | 224.6
13 | 448.6 | 392.2
14 | 498.5 | 561.6
15 | 561.5 | 684.3

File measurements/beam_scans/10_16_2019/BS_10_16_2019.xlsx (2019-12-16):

Beam scan (10-16-2019)
z (inches) | x diameter (\mu m) | y diamter (\mu m)
2 | 725.3 | 1026.3
3 | 731.7 | 1014.3
4 | 735.5 | 1022
5 | 749.1 | 1039.4
6 | 754.5 | 1059.2
7 | 762 | 1070.6
8 | 797.9 | 1101.3
9 | 804.1 | 1103.6
10 | 834 | 1121.7
11 | 851 | 1145.1
12 | 873 | 1157
13 | 906.7 | 1165.9
14 | 936.8 | 1204
15 | 943.1 | 1212.1
16 | 977.4 | 1231
17 | 1006.6 | 1238.3
18 | 1042.7 | 1264
19 | 1071.8 | 1291.3
20 | 1102.7 | 1293.4
21 | 1129.7 | 1324.7
22 | 1172.1 | 1346.3
23 | 1197.5 | 1358.2

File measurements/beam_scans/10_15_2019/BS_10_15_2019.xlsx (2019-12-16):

Beam scan (10-15-2019)
z (inches) | x diameter (\mu m) | y diamter (\mu m)
3 | 603.8 | 618.5
4 | 475.7 | 539.6
5 | 384.4 | 526.6
6 | 424.1 | 450.9
7 | 485.6 | 456.6
8 | 556.7 | 511.4
9 | 626.2 | 561.1
10 | 696.5 | 620.6
11 | 758.3 | 675.1
12 | 837.6 | 743.3
13 | 873.2 | 796.2
14 | 970.3 | 856.2
15 | 1033.5 | 931.8
16 | 1091.2 | 983.3
17 | 1187.7 | 1039.9
18 | 1253.4 | 1105.8
19 | 1334.9 | 1171.8
20 | 1405.3 | 1249

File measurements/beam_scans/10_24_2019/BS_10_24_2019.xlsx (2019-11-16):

Beam scan (10-24-2019) |  | This scan is wrt SM5*
z (inches) | x diameter (\mu m) | y diamter (\mu m)
2 | 919.8 | 1433.5
3 | 881.5 | 1302.5
4 | 810.8 | 1125.9
5 | 776.6 | 1074.5
6 | 745.9 | 1028.9
7 | 660.7 | 935.7
8 | 644.9 | 838
9 | 618.4 | 717.4
10 | 541.9 | 630.5
11 | 545.2 | 549.9
12 | 468.9 | 432.6
13 | 454.2 | 334
14 | 434.3 | 282.2
15 | 434.2 | 372.2
16 | 456.5 | 492.6
17 | 532.4 | 597.6
18 | 594.1 | 692.5
19 | 673.9 | 789
20 | 715.8 | 885.1
21 | 761.3 | 980.8

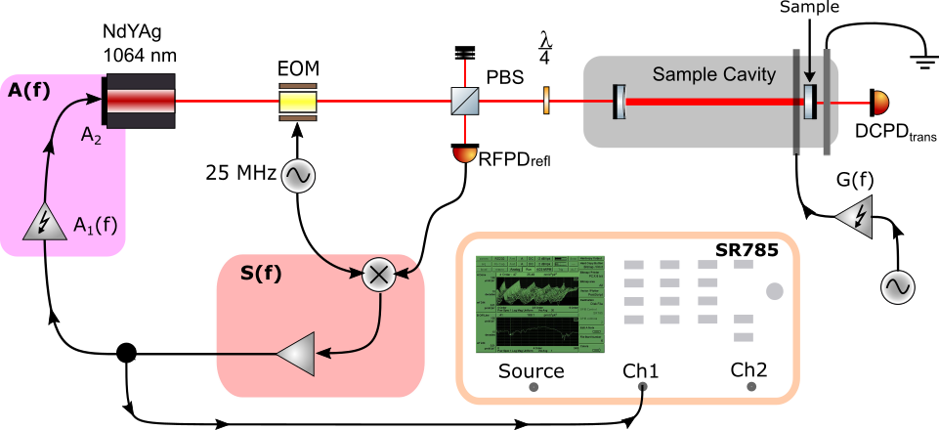
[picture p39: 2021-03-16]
code/notebooks/pockels_calibration/figures/algaas_pockels_single_frequency_calib.png

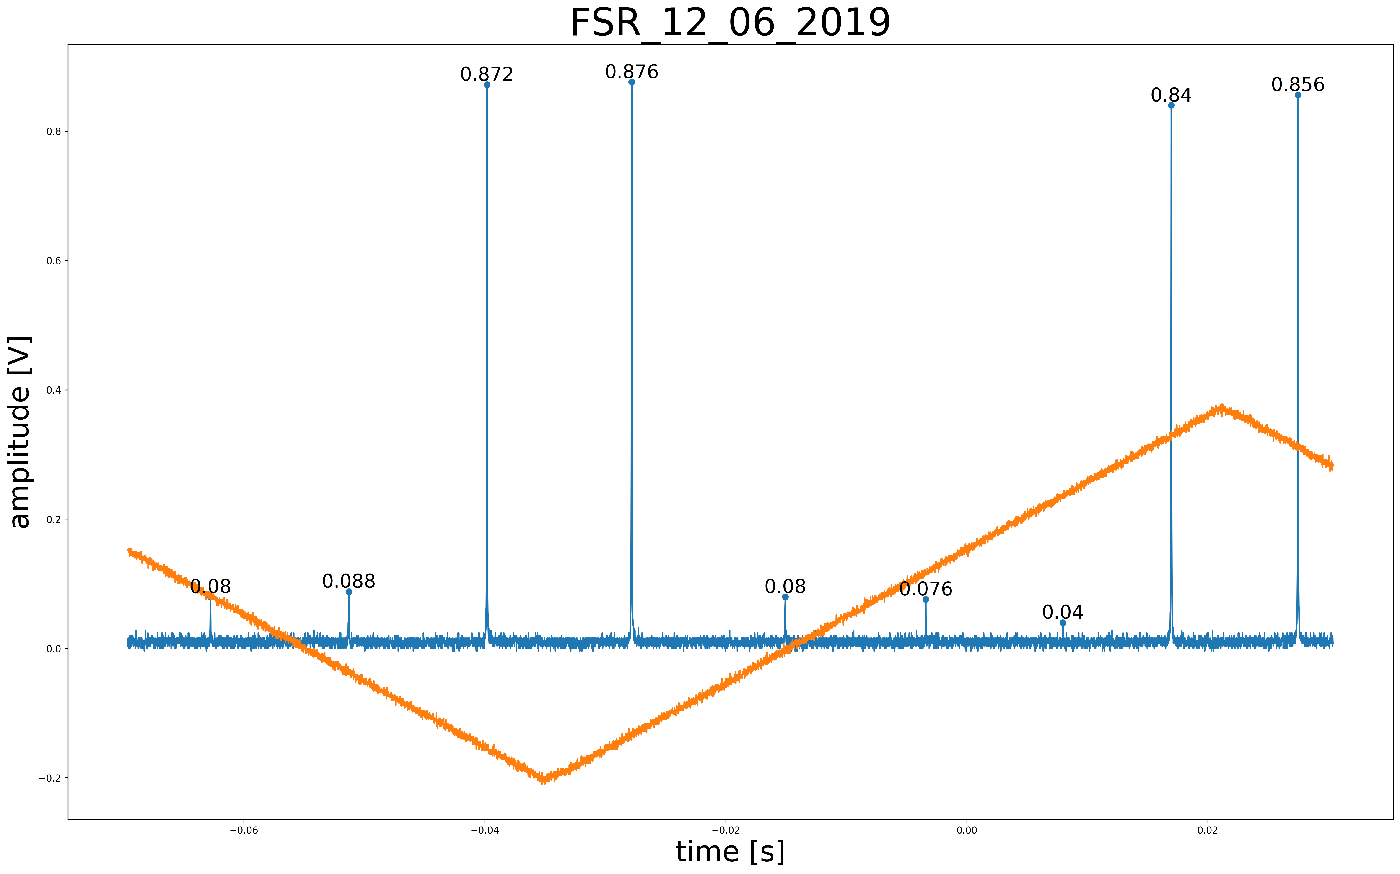
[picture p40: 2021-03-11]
measurements/cavity_scan/12_06_2019/FSR_12_06_2019_results.png

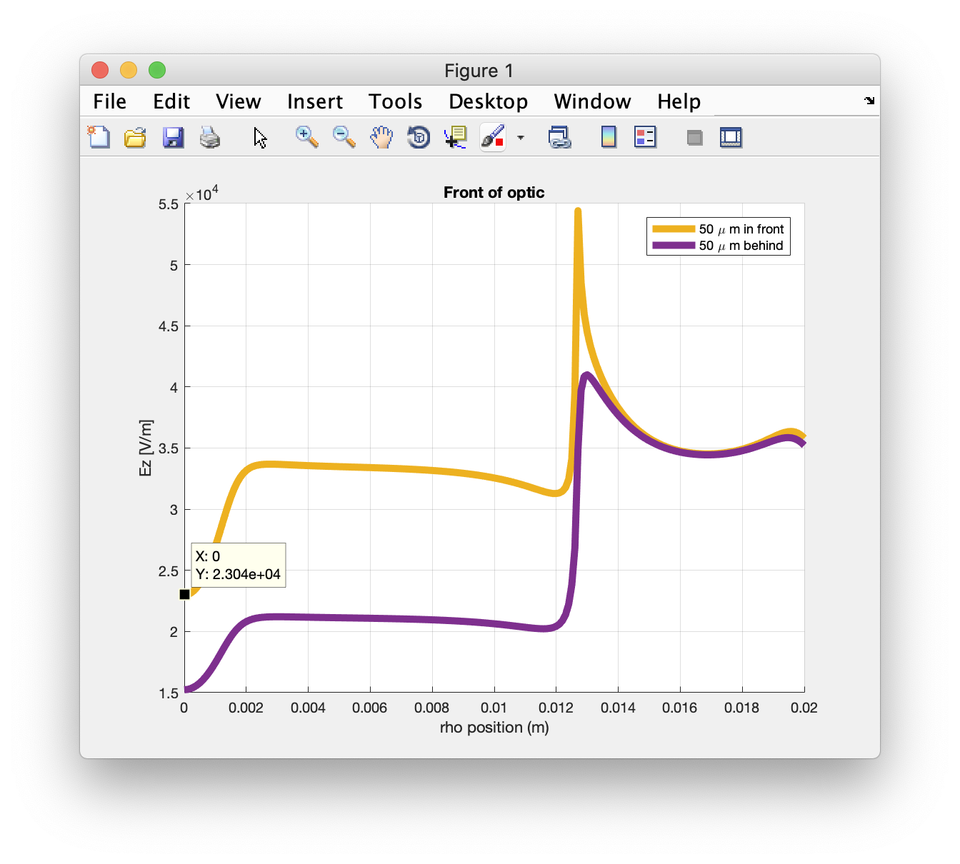
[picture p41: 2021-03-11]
code/fea_electrodes/matlab_script_stefan/poisson/optics_call_results/Screen Shot 2020-05-04 at 7.11.34 PM.png

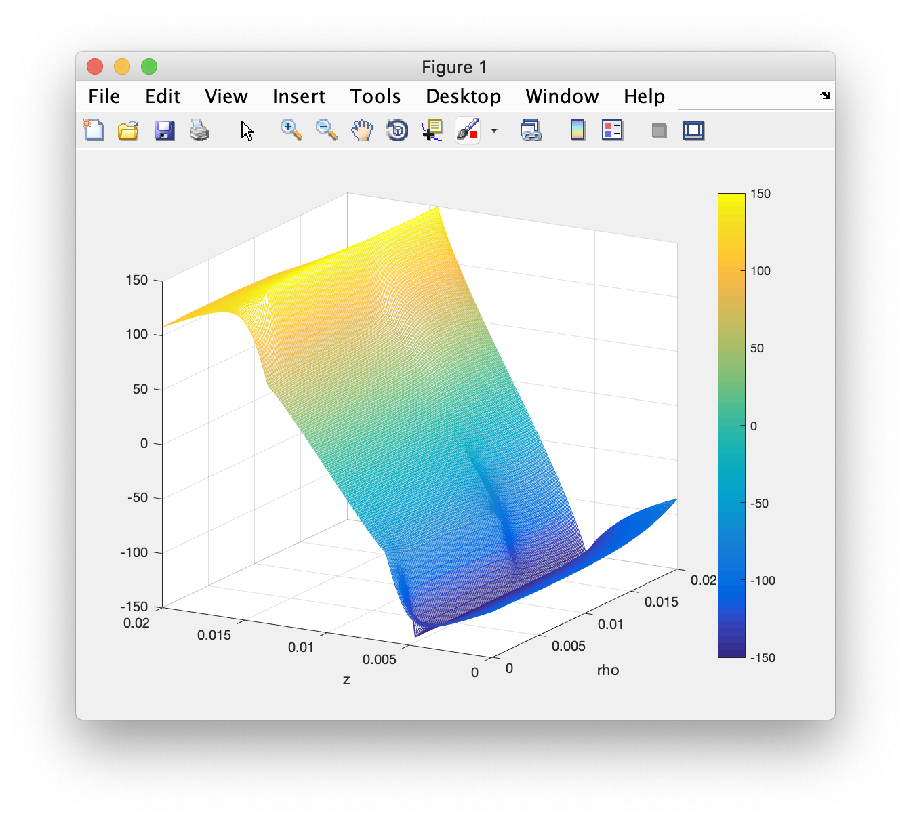
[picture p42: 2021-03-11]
code/fea_electrodes/matlab_script_stefan/poisson/optics_call_results/Screen Shot 2020-05-04 at 7.43.22 PM.png

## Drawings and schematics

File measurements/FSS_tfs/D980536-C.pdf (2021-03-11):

## 12MHZ ELIP LPF

## FP SMA

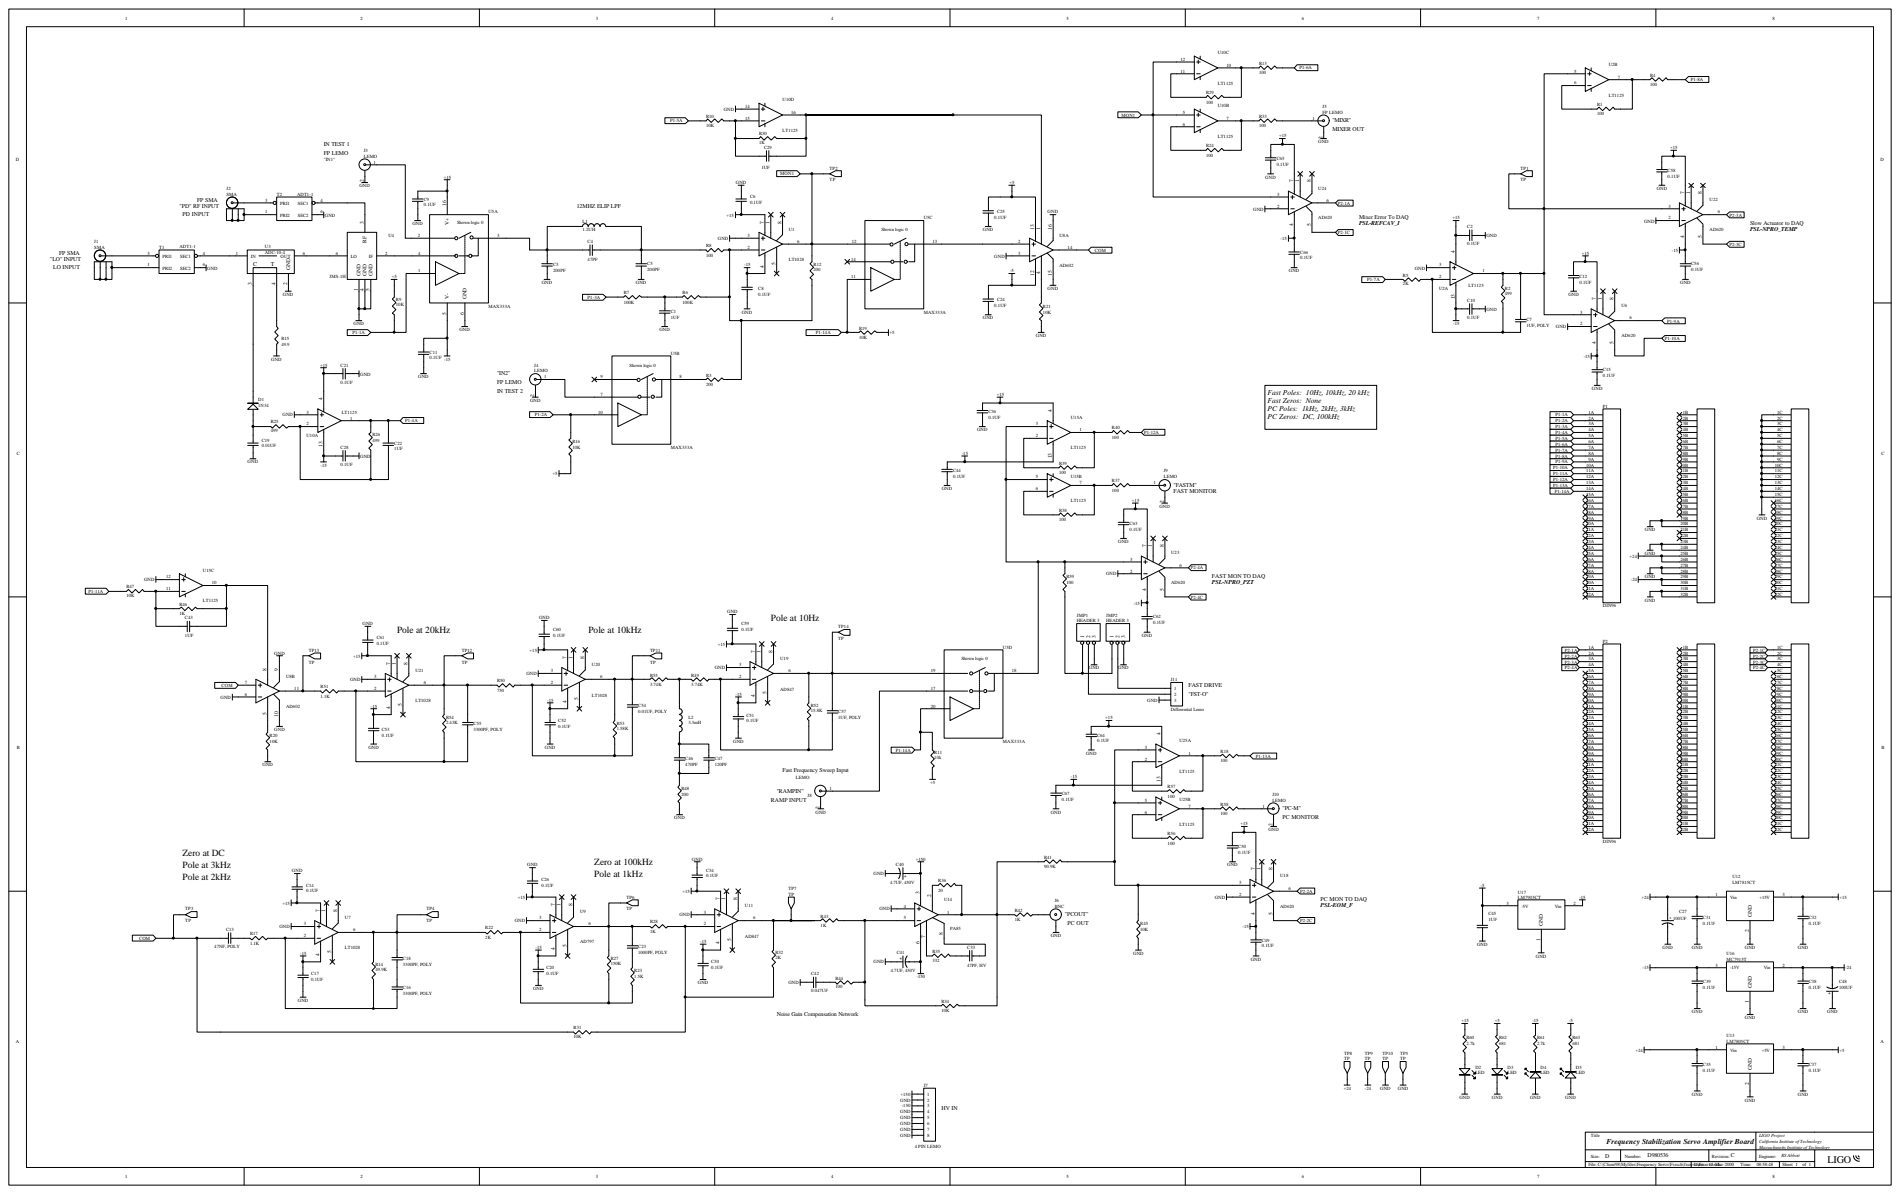
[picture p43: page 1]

Mixer Error To DAQ
PSL-REFCAV_I

Slow Actuator to DAQ
PSL-NPRO_TEMP

FAST MON TO DAQ
PSL-NPRO_PZT

Fast Frequency Sweep Input
LEMO
"RAMPIN"
RAMP INPUT

PC MON TO DAQ
PSL-EOM_F

Noise Gain Compensation Network

Title
Frequency Stabilization Servo Amplifier Board

LIGO Project
California Institute of Technology
Massachusetts Institute of Technology

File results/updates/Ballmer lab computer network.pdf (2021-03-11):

# Room 1 (Physics B233)

# Room 2 (Physics sub-basement B208-W)

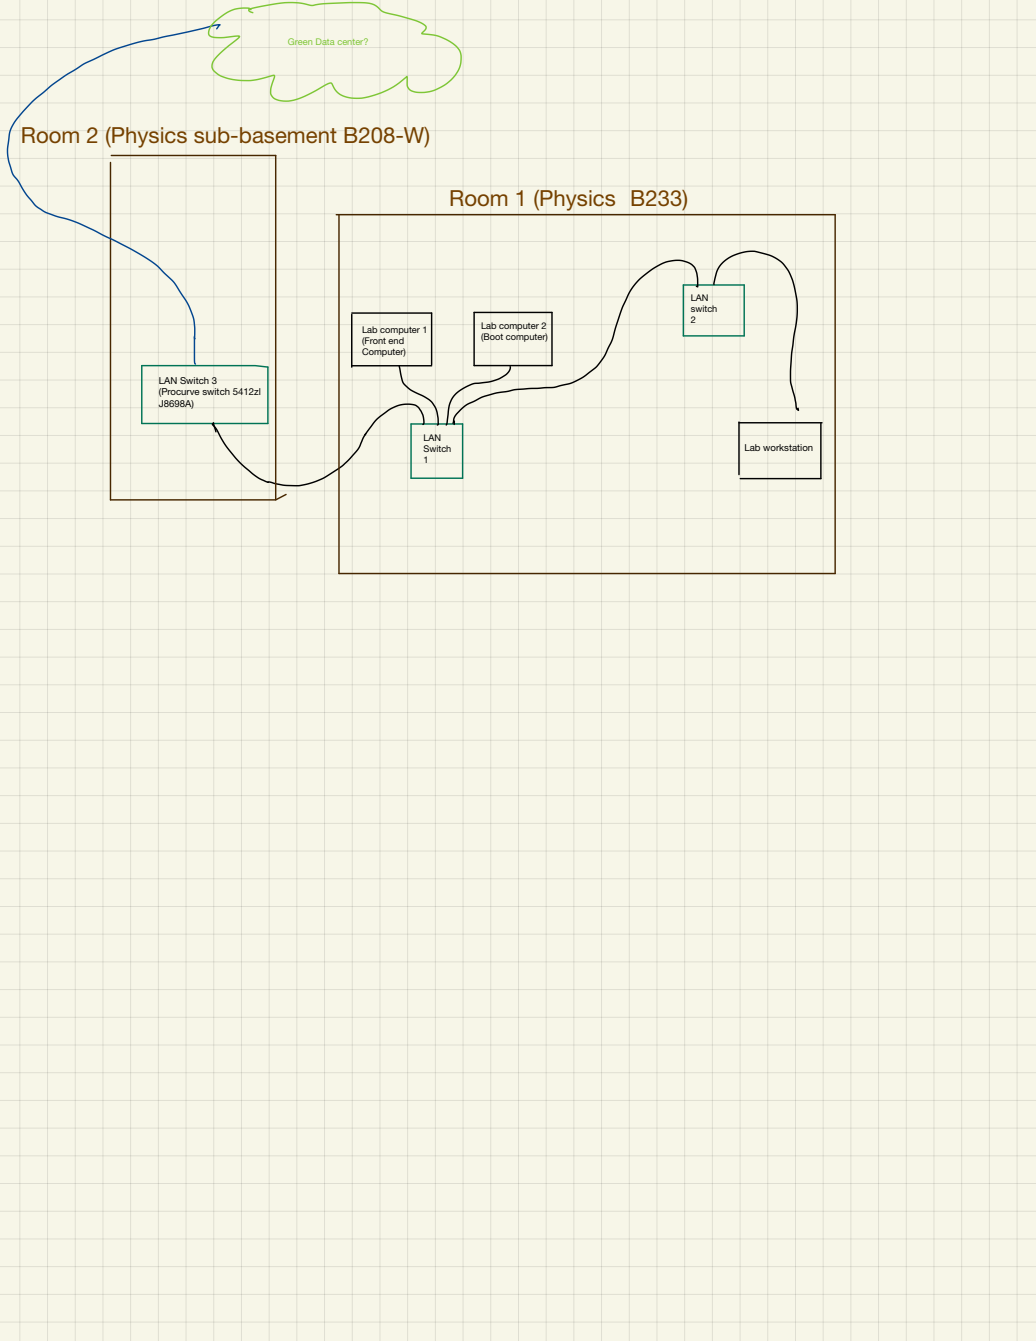
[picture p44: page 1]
Lab computer 1 (Front end Computer); Lab computer 2 (Boot computer); LAN Switch 1; LAN switch 2; LAN Switch 3 (Procurve switch 5412zl J8698A); Lab workstation

Green Data center?

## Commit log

2019-07-26 adding code that will compare numerical solution of charged plates with griffith solution
2019-08-02 Adding fea_split_electrode.py
    This code contains a lot of changes to the finite element analysis code of the two split electrode plates:
    * Now finds the solution of the split electrode problem with different central hole radii
    * All solutions are contained within the U variable. The radii vary along the third dimension
    * Now saves the potential information as well as all relevant metadata needed (in .h5 file in a 'data' directory) to plot the solutions and allows one to easily calculate the electric fields from the potential maps
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2019-09-17 Adding my and Stefan's code for analyzing field strength (@ \rho = 0) as a function of plate separation (d)
2019-09-24 schema v1
    Removed:
    * Unecessary FI and half waveplate
    Added:
    * Mixer and low pass filter for second lockin detection scheme
    * Servo K(s) filter
    * Specified frequency range for function generator (might go lower if not can compete with noise).
    Needed:
    * Possibly some phase shifters
2019-09-26 Started Finesse model of experiment
    * EOM
    * Sample cavity
    * RFPD (trans and refl)
    Notes:
    * Need to have realistic lengths (include proper mode matching)
    * Integrate noises for noise analysis?
    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
2019-09-26 Using a more realistic finesse, changed the x-axis label to the correct label (Detuning) and turned down the modulation depth
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2019-10-26 Mode matching tool added: Adding calculation for power overlap for in-air cavity test
2019-10-27 Adding ipython notebook of beam scan script
    Features:
    * Currently imports a .xlsx file (z (in), x-diam [um], y-diam [um])
    * Performs Nelder-Mead minimization to acquire fit parameters
    * Saves figure in same directory as script (includes fitted waist size and position in the legend)
2019-10-28 Fixes to beam scan fittings script
    * Directory it searches for the .xlsx file was incorrect so I updated it
    * Changed the y-axis label from beam radius to beam size
2019-11-16 Adding beam scan template locally with beam scan fitting script
    [beam_scan_template.xlsx]
2019-12-16 Adding beam scan data and result from 10_15_2019
    [BS_10_15_2019.xlsx]
2019-12-16 Adding beam scan data and results from 10_16_2019
    [BS_10_16_2019.xlsx]
2019-12-16 Adding beam scan data and results from 10_24_2019
    [BS_10_24_2019.xlsx]
2019-12-16 Adding beam scan data and results from 10_28_2018
    [BS_10_28_2019.xlsx]
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2019-12-16 Adding FSS tf measurements from 12_14_2019 (adjusting the laser gain knob and testing the changes while adjusting the thermal loop switch).
2019-12-16 Adding FSS board tf measurement when incorporating the SR560 with a unity gain setting.
2019-12-16 Another CLTF measurment with a 500 mV injection with all of the HEPA filter fans off.
2021-02-23 Adding pockels_cal that contains a calibration function pock_cal which allows for easy calibration of voltage spectra into displacement spectra and saved in an .h5 file in the results directory
2021-02-26 Phase correction to final plot (did not include necessary corrections of loop calibration phase and HVACH3 phase) also included the CAL tf in the .hdf5 file
2021-03-02 Modified model for 66mm x 38mm plate, 3mm plate separation, increased model region and modified transverse field plotting tool.
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2021-03-11 Moved lab_tools folder to code/notebooks/
    [beam_scan_template.xlsx]
2021-03-11 beam scan measurements moved into individual (date labeled) directories
    [BS_10_15_2019.xlsx, BS_10_16_2019.xlsx, BS_10_24_2019.xlsx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]
2021-03-11 completely reorganized repository as of 03/11/2021 still needs more organization, particularly in measurements directory
    [01_12_2021.xlsx, 12_18_2020.xlsx, BS_10_15_2019.xlsx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]
2021-03-12 Adding measurements from 03_10_2021:
    * swept sine measurement with AlGaAs sample installed
    * HVACH1+LPF and HVACH3+pomona
    * disk electrodes capacitence with algaas sample installed
    * OLG
    * constructed a summing board and measured both the spectra output from the board as well as the transfer functions with two separate amplifiers installed (AD829JN offers a flat response at higher fr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
2021-03-13 Adding measurements from 03_12_2020
    * Installed silica-tantala coated HR optic into 3D printed mount (v1) and took the standard measurements for a swept frequency drive (1kHz to 30kHz)
    * Swept frequency measurement
    * Disk electrodes capacitence with sio2-ta2o5 coated optic
    * Also measured the crosstalk between CH1 and CH3. Figure depicting measurement will be attached in another commit.
    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
2021-03-13 Various changes: Now added an additional input for sample type (i.e. algaas vs. sio2ta2o5), also made multiple directory changes to adjust to new formatting
2021-03-13 Adding all .stl files used thus far for 3d printed optical mounts and electrode holders thus far
    [electrode_backing.stl, electrode_brace.stl, optic_and_electrode_mount.stl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]
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2021-03-14 Adding measurements from 03_13_2021
    * Measured noise floor twice and frequency comb with 1Vpk drive and 5Vpk drive
    * Swept frequency measurement with 1Vpk and 5Vpk drives
    * Calibration functions for each measurement were recorded (OLG, HVACH3+pomona, and HVACH1+LPF)
    * Made some separate measurements of the SR560 response (A and B inputs and 50ohm output with bnc T) figure of measurement layout is in relevant directory
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2021-03-14 Adjusted figure so it no longer mentions a specific frequency range (can be added in powerpoint and/or caption if needed)
2021-03-16 LVK code and figures for Electric field estimation from disk electrode poisson model
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2021-03-16 Adding more figures for LVK presentation (updated disk electrode diagrams and updated schematics)
2021-03-24 All measurements taken on 03_23_2021
    These measurements were to compare the frequency sweep measurements with and without the set screws on the 3d printed optical holder with a sio2ta2o5 coated optical sample. Additional frequency sweep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
    [TEK00000.CSV]
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2021-03-26 Adding measurements taken on 03_25_2021
    Further investigations on how we are seeing coherence of electrode drive
    in PDH signal. There are three different swept frequency measurements
    here. State 1 is untouched state since the last measurement (sio2ta2o5
    installed in 3d printed version 1). State 2 is same setup as state 1 but
    split electrodes (not installed) are driven. State 3 is flat sio2ta2o5
    end mirror setup in normal kinematic holder with electrodes setup
    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
2021-04-10 3D print design version 2 (tip-tilt stage attachment)
    [MACOR_bp1.stl, MACOR_bp1_rotated.stl]
2021-04-10 3D print design version 2 (tip-tilt stage attachment) assembly iteration a
    [tip_tilt_mount_pt1.stl, tip_tilt_mount_pt2.stl]
2021-04-14 Backplate central screw hole adjustment (raised by a quarter of an inch) and central hole diameter changed from an inch to three quarters of an inch
    [MACOR_bp_iterationb.stl]
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2021-04-19 Wrong directory for swept measurement. Moved directory to proper sample type (was algaas now sio2tao5
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2021-08-14 pockels calibration jupyter notebook (build still progress) but can run all cells
    [eo_calibrate.yml]
2021-08-15 First working version of .ipynb forgot to replace old .ipynb in last commit. Figures and more detailed information about the calibration will be added.
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2021-08-15 Added math for noise / single frequency drive measurements and added title separating the calibration code section
